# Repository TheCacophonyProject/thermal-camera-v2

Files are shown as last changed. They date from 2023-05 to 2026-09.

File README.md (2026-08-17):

# thermal-camera-v2

## Running tc2-panel.py (KiKit)

`tc2-panel.py` uses [KiKit](https://yaqwsx.github.io/KiKit/) to build the manufacturing panel from the individual board files.

```sh
# Create a venv that inherits the system site-packages (needed for pcbnew)
python3 -m venv --system-site-packages ~/.venvs/kikit
source ~/.venvs/kikit/bin/activate

# Install kikit and the other packages tc2-panel.py needs.
# pcbnewTransition is pinned >=0.5 because older versions assume a pre-KiCad-6
# pcbnew API (e.g. DRAWSEGMENT) and crash against current KiCad.
pip install kikit shapely "pcbnewTransition>=0.5"
```

Once the venv exists, running the panel script again only needs:

```sh
source ~/.venvs/kikit/bin/activate
cd /path/to/thermal-camera-v2
python3 tc2-panel.py
```

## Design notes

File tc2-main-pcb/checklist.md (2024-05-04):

# KiCAD Checklist for tc2-main-pcb

## High Priority
- [ ] Add smaller SMD nut for the modem as it is on the underside and might fall off. Also make it so no copper is on the other side to conduct through the heat when going through the oven.
- [ ] Add battery JLC number
- [x] Add 12 pin power connector JLC number
- [x] Move mounting hole above Modem
- [x] Move LED and button down a mm

## Future Enhancements
- [ ] Bed of nails pads for testing
- [ ] Reduce power usage in sleep mode
- [ ] Disable UART multiplexer chip when Raspberry pi is powered off
- [ ] Make issue about single lable not causing errors when the single lable is attached to multiple pins
- [x] Improve crystal time
- [ ] Add Cacophony logo
- [ ] Add version variable on PCB when it can be set through kicad-cli

## Pre-release checklist
- [ ] Check pinout to power board matches
- [ ] Set TAG
- [ ] Check that components have LCSC part numbers

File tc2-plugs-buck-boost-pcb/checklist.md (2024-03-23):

# KiCAD Checklist for tc2-buck-boost-pcb

## Release Tasks
- [x] Add version variable on PCB

## Future Enhancements
- [x] Better protection for RPi pins
- [ ] Bed of nails pads for testing
- [ ] Add Cacophony logo

## Pre-release checklist
- [ ] Check pinout to power board matches
- [ ] Check power layout
- [ ] Improve courtyard of plugs on bottom side.

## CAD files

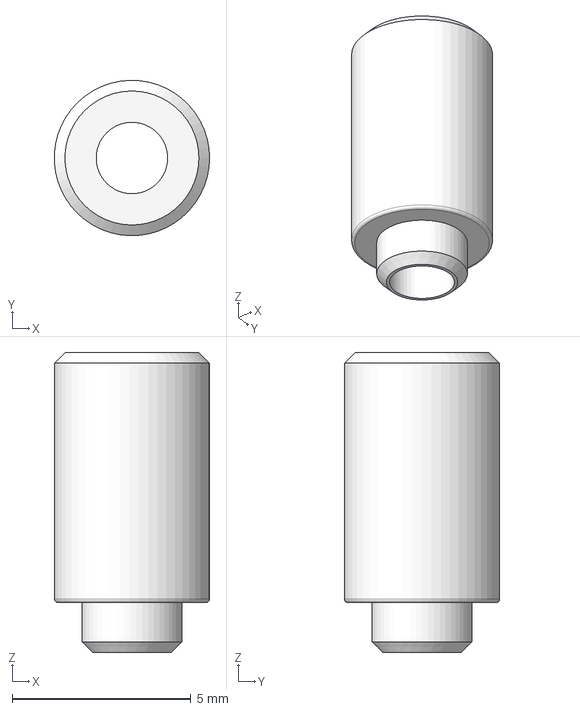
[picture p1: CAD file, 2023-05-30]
tc2-mic-pcb/drawings/7mm_2mm_nut.FCStd
4.35 x 4.35 x 8.40 mm

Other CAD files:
tc2-main-pcb/drawings/tc2-main.pcb.FCStd
tc2-mic-pcb/drawings/tc2-mic-pcb.FCStd
tc2-plugs-buck-boost-pcb/drawings/tc2-plugs-buck-boost-pcb.FCStd
tc2-plugs-pcb/drawings/tc2-plugs-pcb.FCStd
tc2-sim-usb-pcb/drawings/tc2-sim-usb-pcb.FCStd
tc2-sim-usb-pi3-pcb/drawings/tc2-sim-usb-pi3-pcb.FCStd
tc2-sim-usb-pi3-pcb/tc2-sim-usb-pi3-boarder.FCStd

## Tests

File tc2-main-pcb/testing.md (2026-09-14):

# Testing PCB

This is out of date but some parte might still be useful.

Fresh install of Raspberry Pi 64 Bit

## I2C

- `sudo apt install i2c-tools`
- `sudo raspi-conf` enable I2C
- `i2c detect -y 1`
- Check that you can see the addressed of all the devices
- Done

### Temp and Humidity Sensor

- Can get code to test sensor from [tc2-hat-software](https://github.com/TheCacophonyProject/tc2-hat-software)

### RTC

Add to `/etc/boot.conf` on raspberry pi

``` conf
# Enable RTC
dtoverlay=i2c-rtc,pcf8563
```

### Speaker

- Drive GPIO4 HIGH to enable speaker
- `python`

``` python
import RPi.GPIO as GPIO
GPIO.setwarnings(False)
GPIO.setmode(GPIO.BCM)
GPIO.setup(4, GPIO.OUT)
GPIO.output(4, True)
```

- Follow [Adafruit setup instructions](https://learn.adafruit.com/adafruit-max98357-i2s-class-d-mono-amp/raspberry-pi-usage)

### TODO

- EEPROM

## ATtiny1616

### ATtiny1616 RPi Setup

- `sudo apt install python3-pip -y`
- `pip install pymcuprog`
- Free up UART to be used for UPDI connection. Add `dtoverlay=disable-bt` to the end of `/boot/config.txt`
- Disable UART outputting to console: Remove `console=serial0,115200` from `/boot/cmdline.txt` and reboot.
- [pymcprog](https://github.com/microchip-pic-avr-tools/pymcuprog)
- Ping `sudo pymcuprog -d attiny1616 -t uart -u /dev/serial0 ping`
- Erase `sudo pymcuprog -d attiny1616 -t uart -u /dev/serial0 erase`
- Program through UPDI `sudo pymcuprog -d attiny1616 -t uart -u /dev/serial0 write -f ./Blink-attiny1616.ino.t1616.20c0.mD0.v261.hex`
- Note that you should Erase before programming each time.

### ATtiny1616 Testing

- [x] LED
- [] I2C minion
- [] RTC INT
- [] Battery voltage

### ATtiny1616 TODO

- [] Change programming to UPDI instead of ISP
- [] Fix LED pinout for colors
- [] Smaller resistors for LED

## Modem

- [Blog with setup instructions](https://www.elementzonline.com/blog/using-gps-antenna-with-sim7600-4g-lte-modem-v2-0)
- Enable by driving pin `4G_POWER_ON` HIGH
- [Waveshare wiki](https://www.waveshare.com/wiki/SIM7600G-H-M.2)
  - `sudo apt-get install minicom`
  - `sudo minicom -D /dev/ttyUSB2`
  - `AT+CUSBPIDSWITCH=9011,1,1`
  - `sudo dhclient -v usb0`
    AT+CMEE=2

### Modem Testing

- [x] GPS
- [x] 4G

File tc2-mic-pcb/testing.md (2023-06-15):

## Audio
### Microphone
- https://learn.adafruit.com/adafruit-i2s-mems-microphone-breakout/raspberry-pi-wiring-test
- `sudo apt install python3-pip`
- `sudo pip3 install --upgrade adafruit-python-shell`
- `wget https://raw.githubusercontent.com/adafruit/Raspberry-Pi-Installer-Scripts/master/i2smic.py`
- `sudo python3 i2smic.py` Auto load at boot? Y, Reboot now? Y
- Drive GPI17 HIGH to stop LORA module from interfering with the microphone as some of the pins are used for moth modules.
- `python`

Might have to change pins.
```
import RPi.GPIO as GPIO
GPIO.setwarnings(False)
GPIO.setmode(GPIO.BCM)
GPIO.setup(4, GPIO.OUT)
GPIO.output(4, True)
```

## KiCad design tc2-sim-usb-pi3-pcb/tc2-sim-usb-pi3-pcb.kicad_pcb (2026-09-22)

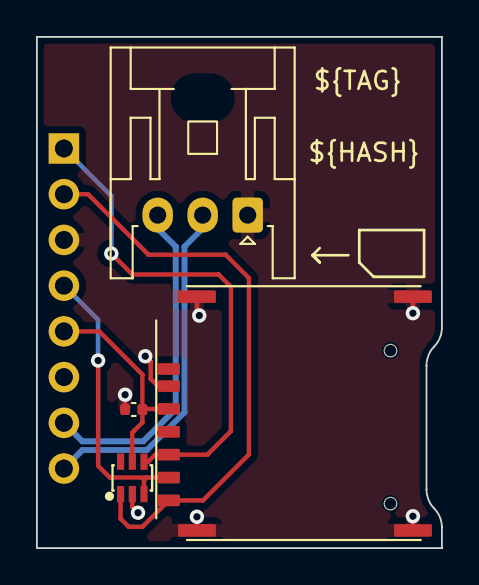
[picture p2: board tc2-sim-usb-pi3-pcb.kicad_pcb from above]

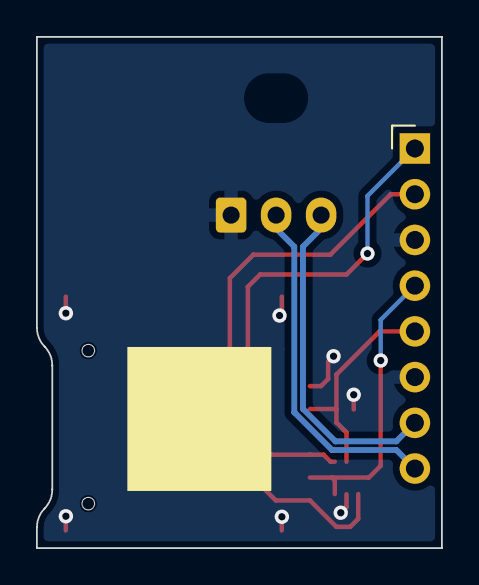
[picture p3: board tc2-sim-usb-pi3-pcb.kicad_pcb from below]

Board: 4 copper layers, 22.5 x 28.4 mm, 6 parts (2 on the bottom side), 7 nets.

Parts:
C1: 220nF; C_0402_1005Metric
D1: SMF05CT1G; SOT-363_L2.0-W1.3-P0.65-LS2.1-BR
J1: Conn_01x08; rpi3-usb-sim-PinHeader_1x08
J2: Conn_01x03; JST_XA_S03B-XASK-1_1x03_P2.50mm_Horizontal
U1: K-DYX-010
U2: JLCPCB_QR_8mm

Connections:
4G_USB_D+: J1.7, J2.3
4G_USB_D-: J1.8, J2.2
GND: C1.1, D1.2, J1.3, J1.6, J2.1, U1.C5 (Gnd), U1.MP, U1.MP_2 (MP), U1.MP_3 (MP), U1.MP_4 (MP)
USIM_CLK: D1.1, J1.2, U1.C3 (CLK)
USIM_DATA: D1.3, J1.4, U1.C7 (I/O)
USIM_RST: D1.4, J1.1, U1.C2 (RST)
USIM_VDD: C1.2, D1.5, J1.5, U1.C1 (Vcc)

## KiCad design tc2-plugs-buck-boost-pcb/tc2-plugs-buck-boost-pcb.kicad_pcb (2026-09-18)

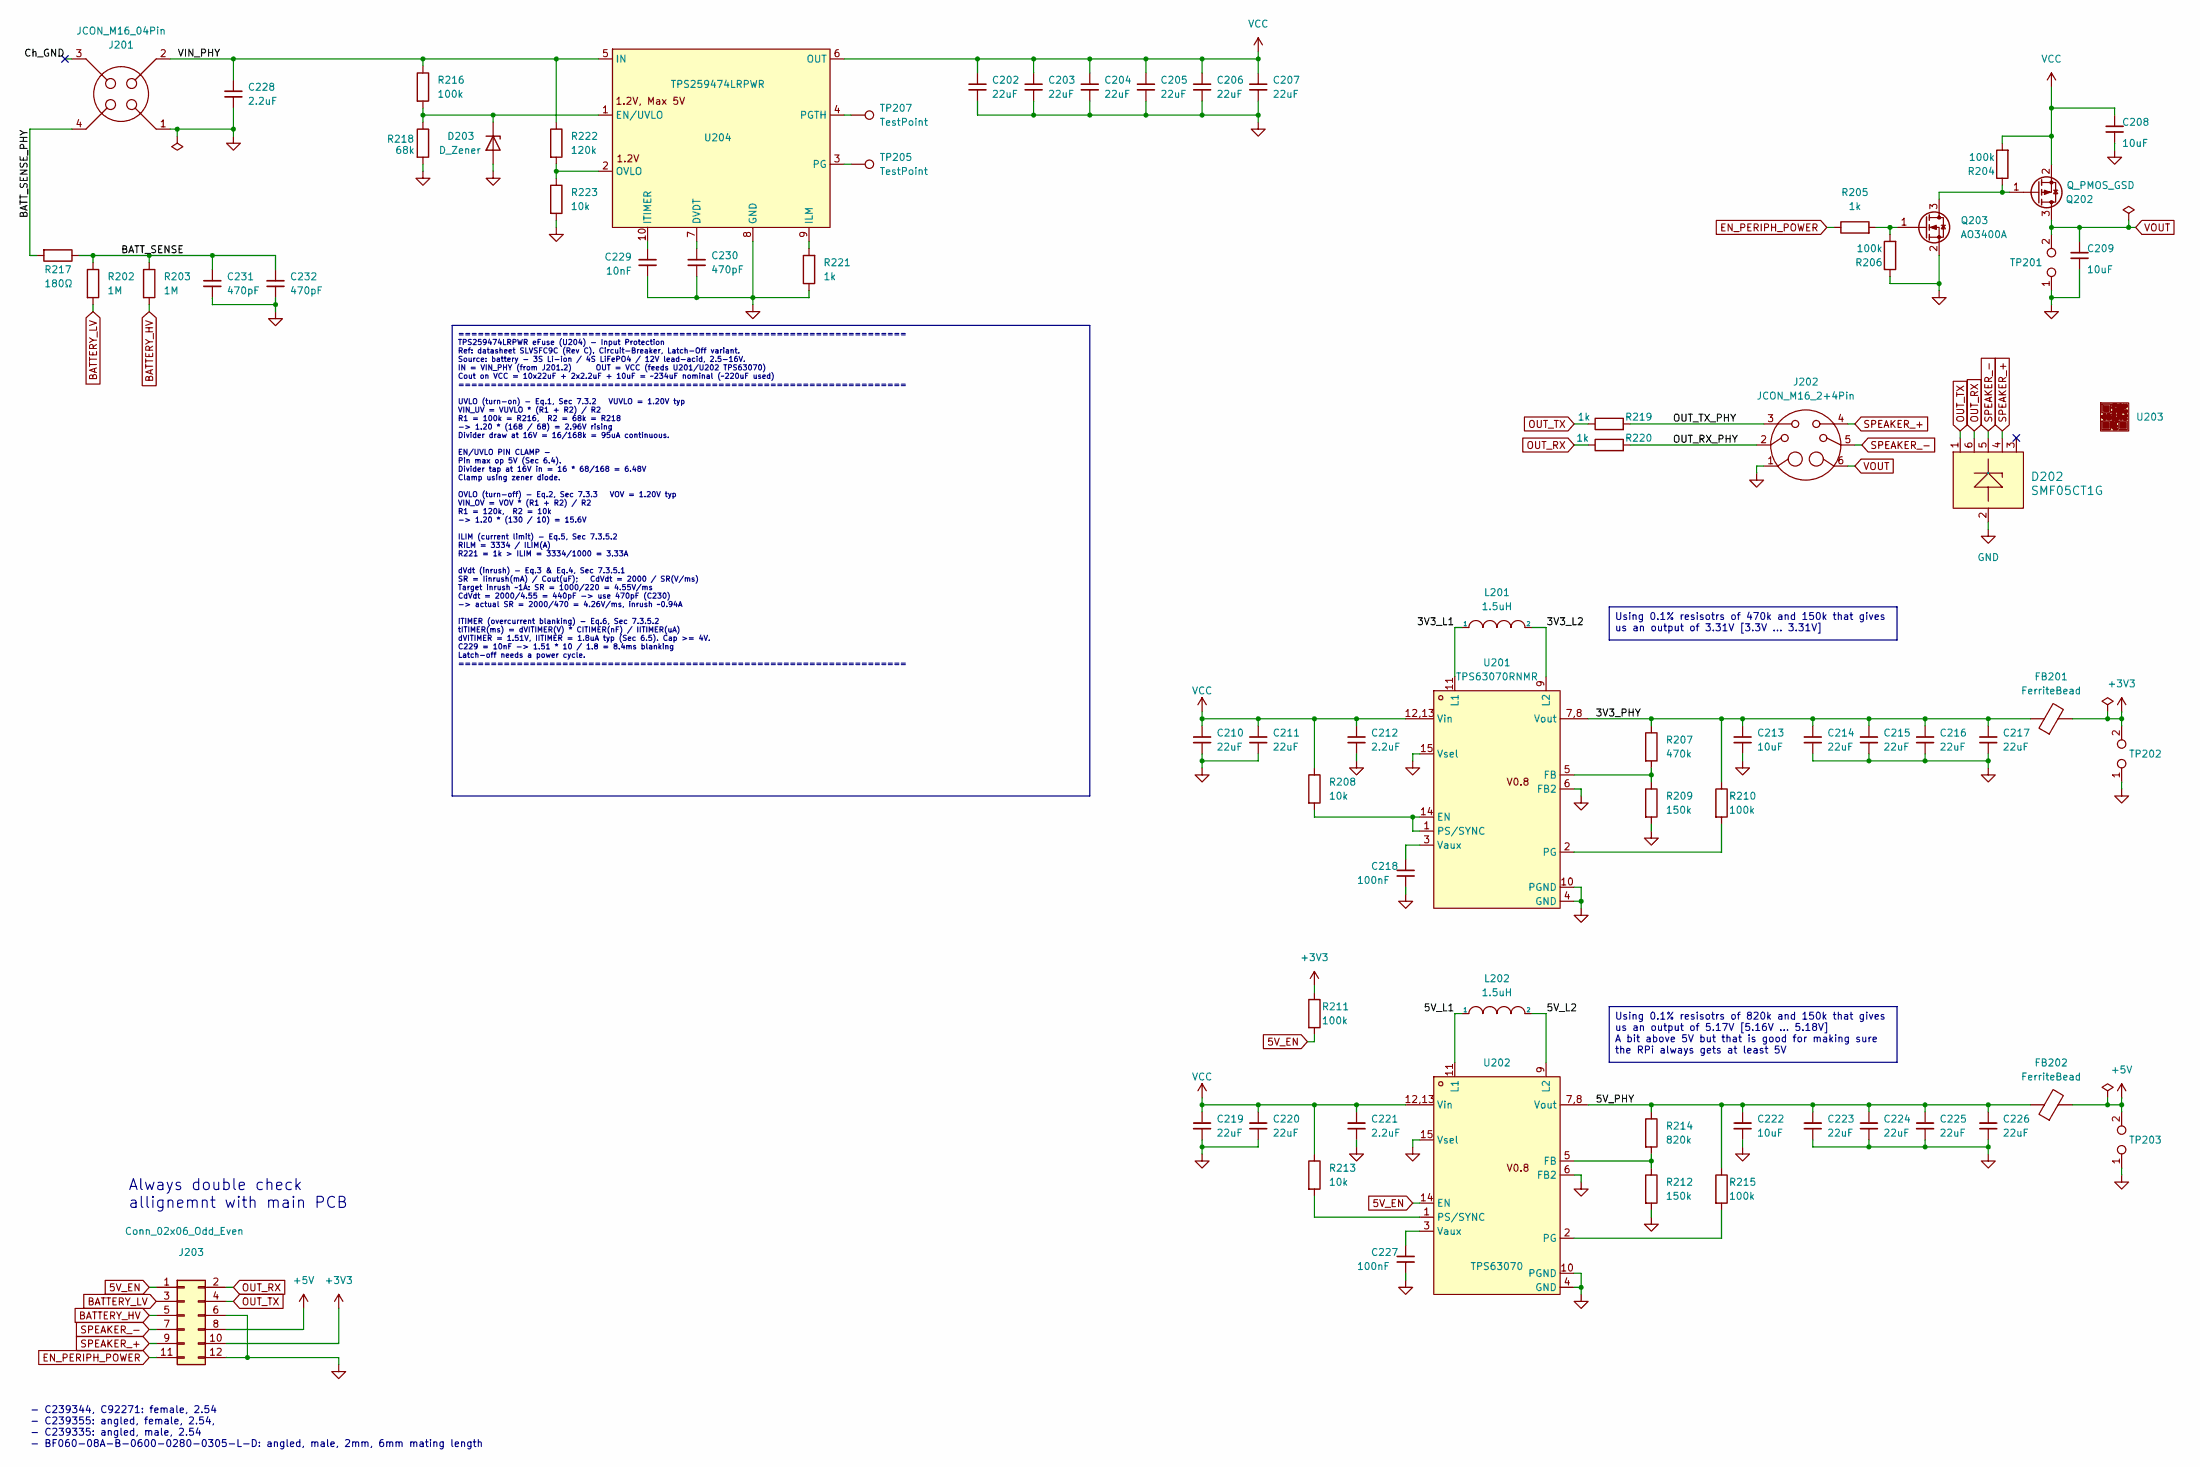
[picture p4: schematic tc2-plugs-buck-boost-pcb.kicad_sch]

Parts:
C202, C203, C204, C205, C206, C207, C210, C211, C219, C220: 22uF; C_0805_2012Metric; LCSC Part C45783
C208, C209: 10uF; C_0603_1608Metric; LCSC Part C19702
C212, C221, C228: 2.2uF; C_0402_1005Metric; LCSC Part C159814
C213, C222: 10uF; C_0402_1005Metric; LCSC Part C15525
C214, C215, C216, C217, C223, C224, C225, C226: 22uF; C_0603_1608Metric; LCSC Part C86295
C218, C227: 100nF; C_0402_1005Metric; LCSC Part C100072
C229: 10nF; C_0402_1005Metric; LCSC Part C15195
C230, C231, C232: 470pF; C_0402_1005Metric; LCSC Part C1537
D202: SMF05CT1G; SOT-363_L2.0-W1.3-P0.65-LS2.1-BR; LCSC Part C15879
D203: D_Zener; D_SOD-323; LCSC Part C136181
FB201, FB202: FerriteBead; L_0805_2012Metric; LCSC Part C76818
J201: JCON_M16_04Pin; jcon-4pin_m16
J202: JCON_M16_2+4Pin; jcon-2+4pin-m16
J203: Conn_02x06_Odd_Even; PinHeader_2x06_P2.00mm_Horizontal; Digikey 2073-BF060-12A-B-0600-0280-0305-L-D-ND
L201, L202: 1.5uH; L_1008_2520Metric; LCSC Part C5179452
Q202: Q_PMOS_GSD; SOT-23; LCSC Part C15127
Q203: AO3400A; SOT-23; LCSC Part C20917
R202, R203: 1M; R_0603_1608Metric; LCSC Part C326730
R204, R206, R210, R211, R215, R216: 100k; R_0402_1005Metric; LCSC Part C25741
R205, R219, R220, R221: 1k; R_0402_1005Metric; LCSC Part C11702
R207: 470k; R_0402_1005Metric; LCSC Part C319591
R208, R213, R223: 10k; R_0402_1005Metric; LCSC Part C25744
R209, R212: 150k; R_0402_1005Metric; LCSC Part C723770
R214: 820k; R_0402_1005Metric; LCSC Part C4042952
R217: 180Ω; R_0402_1005Metric; LCSC Part C38941
R218: 68k; R_0402_1005Metric; LCSC Part C445618
R222: 120k; R_0402_1005Metric; LCSC Part C25750
TP201, TP202, TP203: TestPoint_2Pole; test-point-2p
TP205, TP207: TestPoint; TP_PAD
U201: TPS63070RNMR; TPS63070; LCSC Part C109322
U202: TPS63070; LCSC Part C109322
U203: JLCPCB_QR_8mm
U204: TPS259474LRPWR; VQFN-10_L2.0-W2.0-P0.45-TL; LCSC Part C2864845

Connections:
5V_EN: J203.1, R211.2, U202.14 (EN)
+3V3: FB201.2, J203.10, R211.1, TP202.2
+5V: FB202.2, J203.8, TP203.2
/3V3_L1: L201.1, U201.11 (L1)
/3V3_L2: L201.2, U201.9 (L2)
/3V3_PHY: C213.1, C214.1, C215.1, C216.1, C217.1, FB201.1, R207.1, R210.1, U201.7,8 (Vout)
/5V_L1: L202.1, U202.11 (L1)
/5V_L2: L202.2, U202.9 (L2)
/5V_PHY: C222.1, C223.1, C224.1, C225.1, C226.1, FB202.1, R214.1, R215.1, U202.7,8 (Vout)
/BATT_SENSE: C231.1, C232.1, R202.1, R203.1, R217.1
/BATT_SENSE_PHY: J201.4, R217.2
/Ch_GND: J201.3
/OUT_RX_PHY: J202.2, R220.2
/OUT_TX_PHY: J202.3, R219.2
/VIN_PHY: C228.1, J201.2, R216.1, R222.1, U204.5 (IN)
BATTERY_HV: J203.5, R203.2
BATTERY_LV: J203.3, R202.2
EN_PERIPH_POWER: J203.11, R205.1
GND: C202.2, C203.2, C204.2, C205.2, C206.2, C207.2, C208.2, C209.2, C210.2, C211.2, C212.2, C213.2, C214.2, C215.2, C216.2, C217.2, C218.2, C219.2, C220.2, C221.2, C222.2, C223.2, C224.2, C225.2, C226.2, C227.2, C228.2, C229.2, C230.2, C231.2, C232.2, D202.2, D203.2 (A), J201.1, J202.1, J203.6, J203.12, Q203.2 (S), R206.1, R209.2, R212.2, R218.2, R221.1, R223.2, TP201.1, TP202.1, TP203.1, U201.4 (GND), U201.6 (FB2), U201.10 (PGND), U201.15 (Vsel), U202.4 (GND), U202.6 (FB2), U202.10 (PGND), U202.15 (Vsel), U204.8 (GND)
unnamed: D203.1 (K), R216.2, R218.1, U204.1 (EN/UVLO)
unnamed: Q202.1 (G), Q203.3 (D), R204.1
unnamed: Q203.1 (G), R205.2, R206.2
unnamed: R208.2, U201.1 (PS/SYNC), U201.14 (EN)
unnamed: R207.2, R209.1, U201.5 (FB)
unnamed: R210.2, U201.2 (PG)
unnamed: C218.1, U201.3 (Vaux)
unnamed: R212.1, R214.2, U202.5 (FB)
unnamed: R215.2, U202.2 (PG)
unnamed: R213.2, U202.1 (PS/SYNC)
unnamed: C227.1, U202.3 (Vaux)
unnamed: C230.1, U204.7 (DVDT)
unnamed: R221.2, U204.9 (ILM)
unnamed: C229.1, U204.10 (ITIMER)
unnamed: R222.2, R223.1, U204.2 (OVLO)
unnamed: TP205.1 (1_1), U204.3 (PG)
unnamed: TP207.1 (1_1), U204.4 (PGTH)
OUT_RX: D202.6, J203.2, R220.1
OUT_TX: D202.1, J203.4, R219.1
SPEAKER_+: D202.4, J202.4, J203.9
SPEAKER_-: D202.5, J202.5, J203.7
VCC: C202.1, C203.1, C204.1, C205.1, C206.1, C207.1, C208.1, C210.1, C211.1, C212.1, C219.1, C220.1, C221.1, Q202.2 (S), R204.2, R208.1, R213.1, U201.12,13 (Vin), U202.12,13 (Vin), U204.6 (OUT)
VOUT: C209.1, J202.6, Q202.3 (D), TP201.2

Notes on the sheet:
Always double check allignemnt with main PCB
- C239344, C92271: female, 2.54 - C239355: angled, female, 2.54, - C239335: angled, male, 2.54 - BF060-08A-B-0600-0280-0305-L-D: angled, male, 2mm, 6mm mating length
===================================================================== TPS259474LRPWR eFuse (U204) - Input Protection Ref: datasheet SLVSFC9C (Rev C). Circuit-Breaker, Latch-Off variant. Source: battery - 3S Li-ion / 4S LiFePO4 / 12V lead-acid, 2.5-16V. IN = VIN_PHY (from J201.2) OUT = VCC (feeds U2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
Using 0.1% resisotrs of 470k and 150k that gives us an output of 3.31V [3.3V ... 3.31V]
Using 0.1% resisotrs of 820k and 150k that gives us an output of 5.17V [5.16V ... 5.18V] A bit above 5V but that is good for making sure the RPi always gets at least 5V

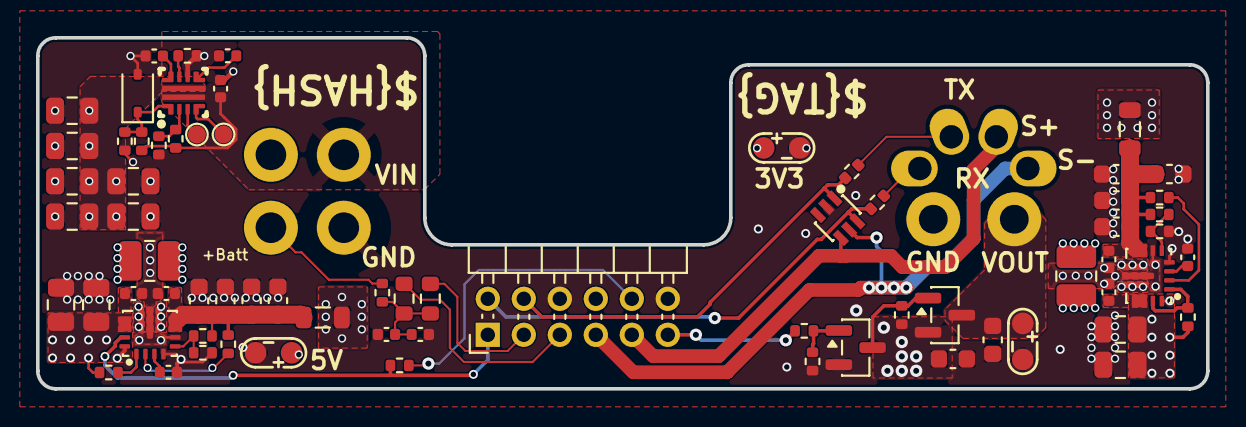
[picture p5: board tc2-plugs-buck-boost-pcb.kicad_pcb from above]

Board: 6 copper layers, 65.0 x 19.5 mm, 73 parts (1 on the bottom side), 41 nets.

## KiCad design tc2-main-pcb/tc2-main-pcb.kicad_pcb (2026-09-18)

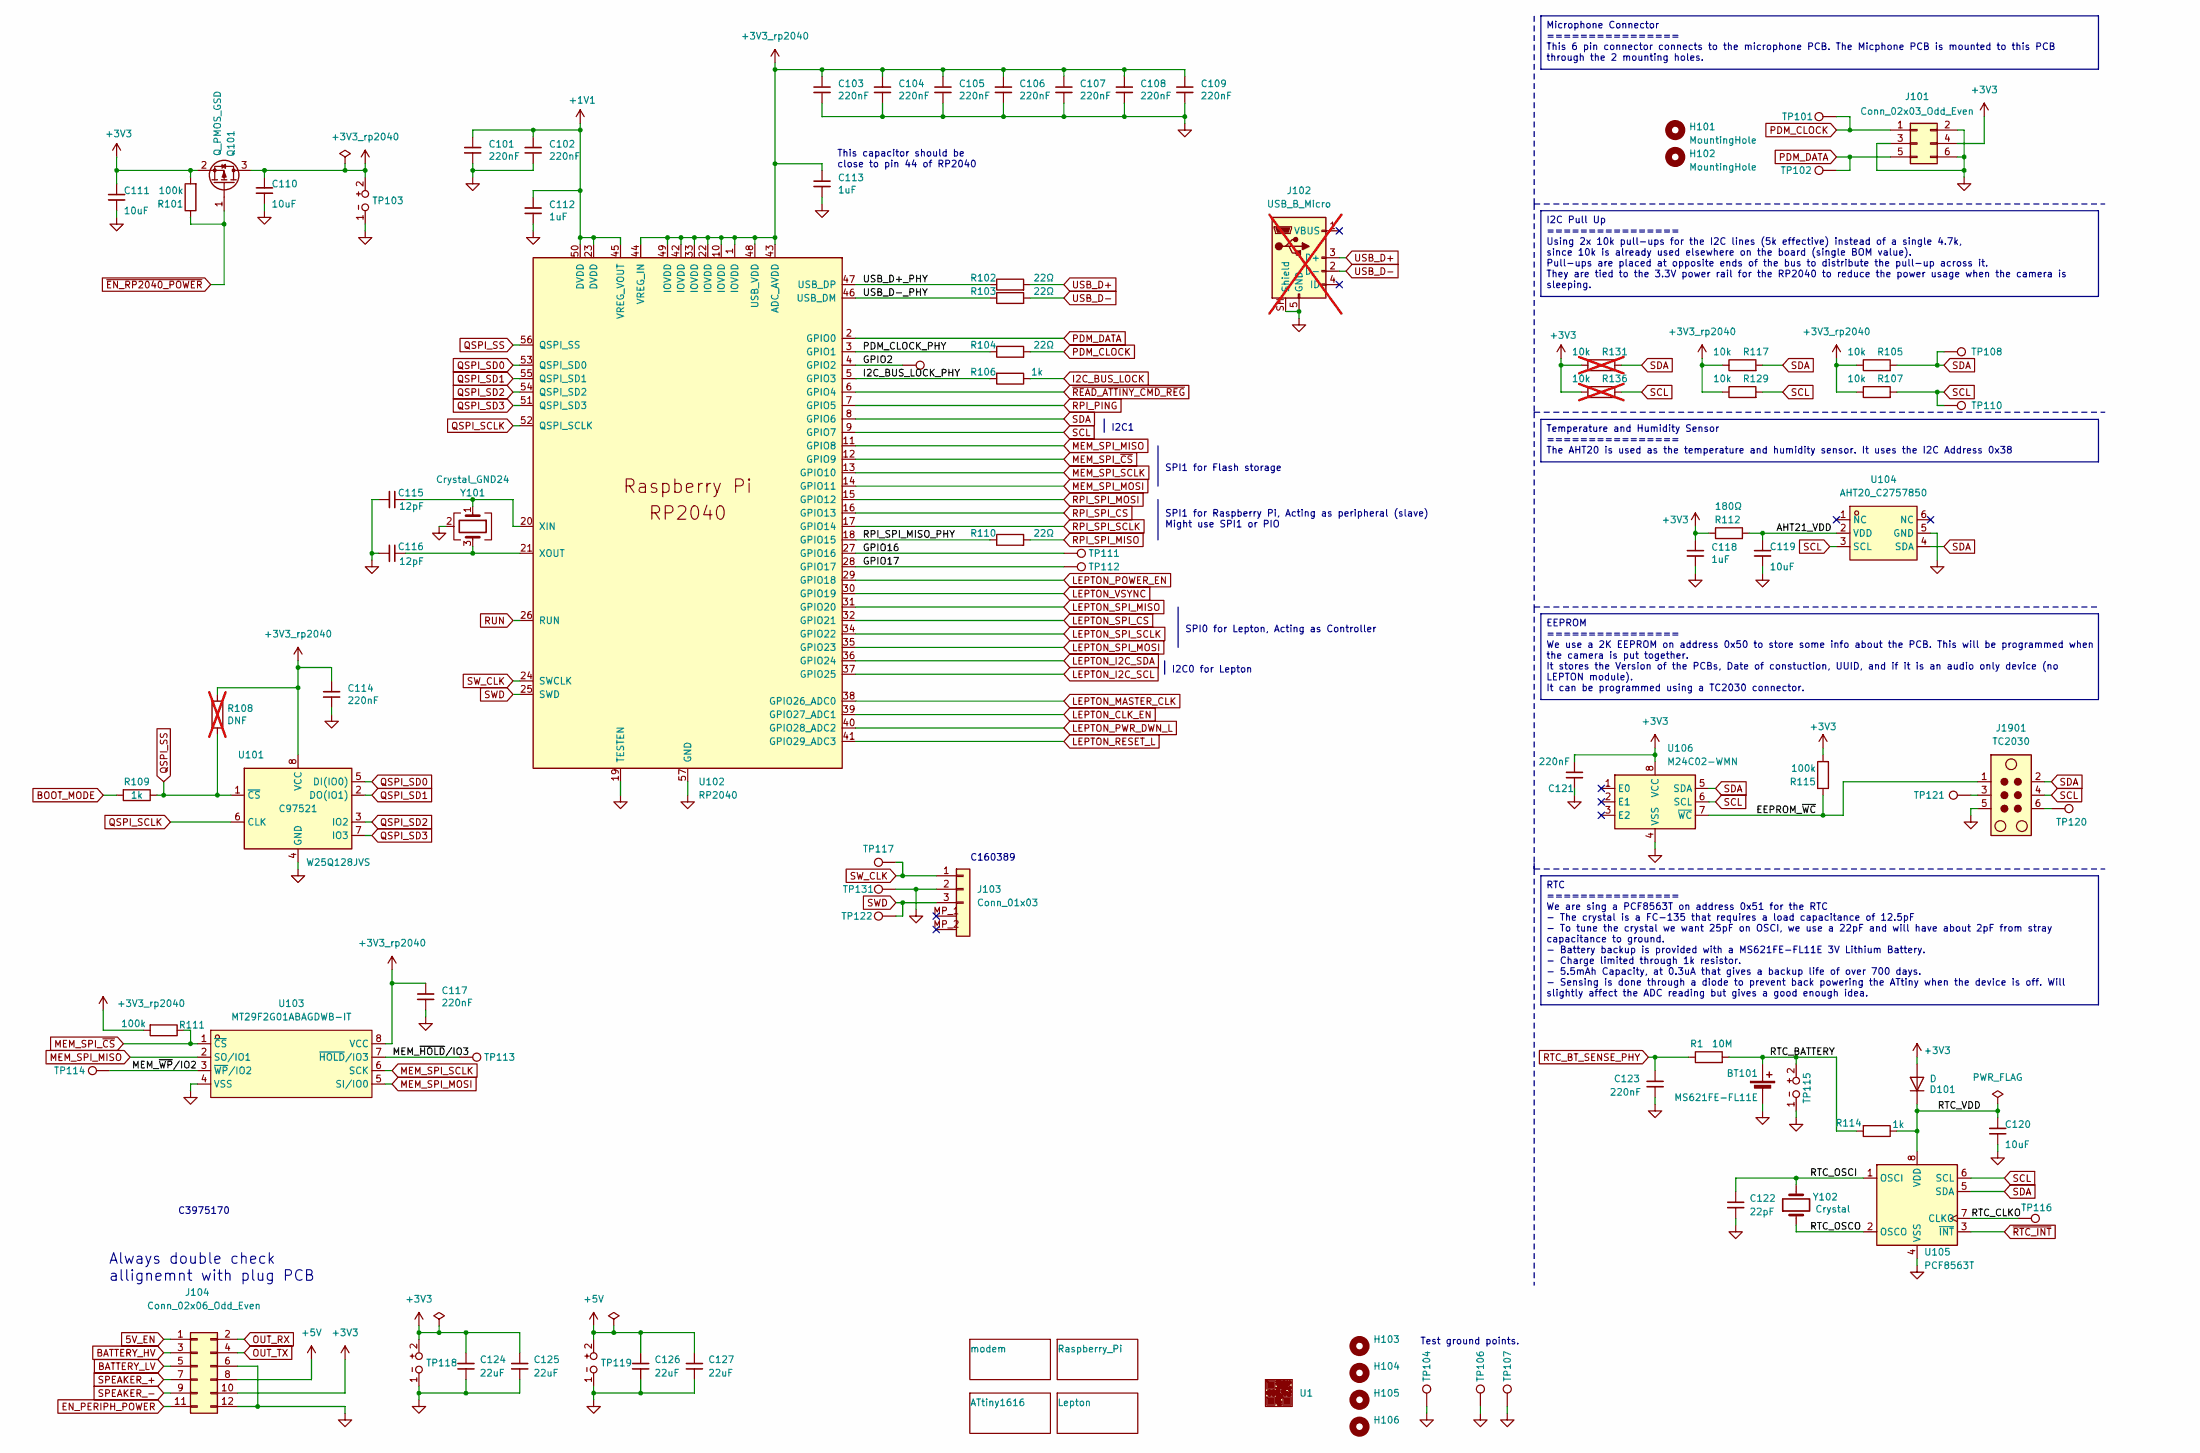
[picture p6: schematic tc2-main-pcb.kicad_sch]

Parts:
BT101: MS621FE-FL11E; CAP-SMD_FL11E; LCSC Part C80909
C101, C102, C103, C104, C105, C106, C107, C108, C109, C114, C117, C121, C123: 220nF; C_0402_1005Metric; LCSC Part C16772
C110, C111, C119, C120: 10uF; C_0603_1608Metric; LCSC Part C19702
C112, C113, C118: 1uF; C_0402_1005Metric; LCSC Part C52923
C115, C116: 12pF; C_0402_1005Metric; LCSC Part C1547
C122: 22pF; C_0402_1005Metric; LCSC Part C1555
C124, C125, C126, C127: 22uF; C_0603_1608Metric; LCSC Part C86295
D101: D; D_SOD-523; LCSC Part C668989
H101, H102: MountingHole; MountingHole_2.2mm_M2
H103, H104, H105, H106: MountingHole; MountingHole_3.2mm_M3
J101: Conn_02x03_Odd_Even; mic-pcb; LCSC Part C3975129
J102: USB_B_Micro; MICRO-USB-TH_MICRO-USB-A14; LCSC Part C145795; not fitted
J103: Conn_01x03; JST_SH_BM03B-SRSS-TB_1x03-1MP_P1.00mm_Vertical; LCSC Part C160389
J104: Conn_02x06_Odd_Even; power-pcb-3.1; Digikey BF100-12-A-D-1-0640-L-C
J1901: TC2030; Tag-Connect_TC2030-IDC-NL_2x03_P1.27mm_Vertical
Q101: Q_PMOS_GSD; SOT-23; LCSC Part C15127
R1: 10M; R_0402_1005Metric; LCSC Part C274900
R101, R111, R115: 100k; R_0402_1005Metric; LCSC Part C25741
R102, R103, R104, R110: 22Ω; R_0402_1005Metric; LCSC Part C25092
R105, R107, R117, R129: 10k; R_0402_1005Metric; LCSC Part C25744
R106, R109, R114: 1k; R_0402_1005Metric; LCSC Part C11702
R108: DNF; R_0402_1005Metric; not fitted
R112: 180Ω; R_0402_1005Metric; LCSC Part C38941
R131, R136: 10k; R_0402_1005Metric; LCSC Part C25744; not fitted
TP101, TP102, TP108, TP110, TP117, TP120, TP121, TP122, TP131: TestPoint; TestPoint_Pad_D1.0mm
TP103, TP115, TP118, TP119: TP_2P; test-point-2p
TP104, TP106, TP107: TestPoint; TestPoint_Loop_D2.54mm_Drill1.5mm_Beaded
TP109, TP111, TP112, TP113, TP114, TP116: TestPoint; TP
U1: JLCPCB_QR_8mm
U101: W25Q128JVS; SOIC-8_5.3x5.3mm_P1.27mm; LCSC Part C97521
U102: RP2040; RP2040-QFN-56; LCSC Part C2040
U103: MT29F2G01ABAGDWB-IT; U-PDFN-8_L6.0-W8.0-P1.27-BL; JLC Part Extended Part
U104: AHT20_C2757850; SENSOR-SMD_L3.0-W3.0-P1.00-BR; LCSC Part C2757850
U105: PCF8563T; SOIC-8_3.9x4.9mm_P1.27mm; LCSC Part C7440
U106: M24C02-WMN; SOIC-8_3.9x4.9mm_P1.27mm; LCSC Part C7562
Y101: Crystal_GND24; Crystal_SMD_3225-4Pin_3.2x2.5mm; LCSC Part C9002
Y102: Crystal; Crystal_SMD_3215-2Pin_3.2x1.5mm; LCSC Part C32346

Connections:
5V_EN: J104.1; also elsewhere on the board
+1V1: C101.1, C102.1, C112.1, U102.23 (DVDD), U102.45 (VREG_VOUT), U102.50 (DVDD)
+3V3: C111.1, C118.1, C121.2, C124.1, C125.1, D101.2 (A), J101.4, J104.10, Q101.2 (S), R101.2, R112.1, R115.2, R131.1, R136.1, TP118.2, U106.8 (VCC); also elsewhere on the board
+3V3_rp2040: C103.1, C104.1, C105.1, C106.1, C107.1, C108.1, C109.1, C110.1, C113.1, C114.1, C117.1, Q101.3 (D), R105.1, R107.1, R108.1, R111.2, R117.1, R129.1, TP103.2, U101.8 (VCC), U102.1 (IOVDD), U102.10 (IOVDD), U102.22 (IOVDD), U102.33 (IOVDD), U102.42 (IOVDD), U102.43 (ADC_AVDD), U102.44 (VREG_IN), U102.48 (USB_VDD), U102.49 (IOVDD), U103.8 (VCC)
+5V: C126.1, C127.1, J104.8, TP119.2; also elsewhere on the board
/AHT21_VDD: C119.1, R112.2, U104.2 (VDD)
/EEPROM_~WC: J1901.1, R115.1, U106.7 (~WC)
/GPIO2: TP109.1 (1_1), U102.4 (GPIO2)
/GPIO16: TP111.1 (1_1), U102.27 (GPIO16)
/GPIO17: TP112.1 (1_1), U102.28 (GPIO17)
/I2C_BUS_LOCK_PHY: R106.2, U102.5 (GPIO3)
/MEM_~HOLD/IO3: TP113.1 (1_1), U103.7 (~HOLD/IO3)
/MEM_~WP/IO2: TP114.1 (1_1), U103.3 (~WP/IO2)
/PDM_CLOCK_PHY: R104.1, U102.3 (GPIO1)
/RPI_SPI_MISO_PHY: R110.1, U102.18 (GPIO15)
/RTC_BATTERY: BT101.1 (+), R1.2, R114.2, TP115.2
/RTC_CLKO: TP116.1 (1_1), U105.7 (CLKO)
/RTC_OSCI: C122.1, U105.1 (OSCI), Y102.2
/RTC_OSCO: U105.2 (OSCO), Y102.1
/RTC_VDD: C120.1, D101.1 (K), R114.1, U105.8 (VDD)
/USB_D+_PHY: R102.1, U102.47 (USB_DP)
/USB_D-_PHY: R103.1, U102.46 (USB_DM)
BATTERY_HV: J104.3; also elsewhere on the board
BATTERY_LV: J104.5; also elsewhere on the board
BOOT_MODE: R109.2; also elsewhere on the board
EN_PERIPH_POWER: J104.11; also elsewhere on the board
GND: BT101.2 (-), C101.2, C102.2, C103.2, C104.2, C105.2, C106.2, C107.2, C108.2, C109.2, C110.2, C111.2, C112.2, C113.2, C114.2, C115.1, C116.1, C117.2, C118.2, C119.2, C120.2, C121.1, C122.2, C123.2, C124.2, C125.2, C126.2, C127.2, J101.2, J101.3, J101.6, J102.5 (GND), J102.SH (Shield), J103.2, J104.6, J104.12, J1901.5, TP103.1, TP104.1 (1_1), TP106.1 (1_1), TP107.1 (1_1), TP115.1, TP118.1, TP119.1, TP131.1 (1_1), U101.4 (GND), U102.19 (TESTEN), U102.57 (GND), U103.4 (VSS), U104.5 (GND), U105.4 (VSS), U106.4 (VSS), Y101.2 (G), Y101.4 (G); also elsewhere on the board
I2C_BUS_LOCK: R106.1; also elsewhere on the board
LEPTON_CLK_EN: U102.39 (GPIO27_ADC1); also elsewhere on the board
LEPTON_I2C_SCL: U102.37 (GPIO25); also elsewhere on the board
LEPTON_I2C_SDA: U102.36 (GPIO24); also elsewhere on the board
LEPTON_MASTER_CLK: U102.38 (GPIO26_ADC0); also elsewhere on the board
LEPTON_POWER_EN: U102.29 (GPIO18); also elsewhere on the board
LEPTON_PWR_DWN_L: U102.40 (GPIO28_ADC2); also elsewhere on the board
LEPTON_RESET_L: U102.41 (GPIO29_ADC3); also elsewhere on the board
LEPTON_SPI_CS: U102.32 (GPIO21); also elsewhere on the board
LEPTON_SPI_MISO: U102.31 (GPIO20); also elsewhere on the board
LEPTON_SPI_MOSI: U102.35 (GPIO23); also elsewhere on the board
LEPTON_SPI_SCLK: U102.34 (GPIO22); also elsewhere on the board
LEPTON_VSYNC: U102.30 (GPIO19); also elsewhere on the board
MEM_SPI_MISO: U102.11 (GPIO8), U103.2 (SO/IO1)
MEM_SPI_MOSI: U102.14 (GPIO11), U103.5 (SI/IO0)
MEM_SPI_SCLK: U102.13 (GPIO10), U103.6 (SCK)
MEM_SPI_~CS: R111.1, U102.12 (GPIO9), U103.1 (~CS)
unnamed: J1901.3, TP121.1 (1_1)
unnamed: J1901.6, TP120.1 (1_1)
unnamed: C115.2, U102.20 (XIN), Y101.1
unnamed: C116.2, U102.21 (XOUT), Y101.3
OUT_RX: J104.2; also elsewhere on the board
OUT_TX: J104.4; also elsewhere on the board
PDM_CLOCK: J101.1, R104.2, TP101.1 (1_1)
PDM_DATA: J101.5, TP102.1 (1_1), U102.2 (GPIO0)
QSPI_SCLK: U101.6 (CLK), U102.52 (QSPI_SCLK)
QSPI_SD0: U101.5 (DI(IO0)), U102.53 (QSPI_SD0)
QSPI_SD1: U101.2 (DO(IO1)), U102.55 (QSPI_SD1)
QSPI_SD2: U101.3 (IO2), U102.54 (QSPI_SD2)
QSPI_SD3: U101.7 (IO3), U102.51 (QSPI_SD3)
QSPI_SS: R108.2, R109.1, U101.1 (~CS), U102.56 (QSPI_SS)
RPI_PING: U102.7 (GPIO5); also elsewhere on the board
RPI_SPI_CS: U102.16 (GPIO13); also elsewhere on the board
RPI_SPI_MISO: R110.2; also elsewhere on the board
RPI_SPI_MOSI: U102.15 (GPIO12); also elsewhere on the board
RPI_SPI_SCLK: U102.17 (GPIO14); also elsewhere on the board
RTC_BT_SENSE_PHY: C123.1, R1.1; also elsewhere on the board
RUN: U102.26 (RUN); also elsewhere on the board
SCL: J1901.4, R107.2, R129.2, R136.2, TP110.1 (1_1), U102.9 (GPIO7), U104.3 (SCL), U105.6 (SCL), U106.6 (SCL); also elsewhere on the board
SDA: J1901.2, R105.2, R117.2, R131.2, TP108.1 (1_1), U102.8 (GPIO6), U104.4 (SDA), U105.5 (SDA), U106.5 (SDA); also elsewhere on the board
SPEAKER_+: J104.7; also elsewhere on the board
SPEAKER_-: J104.9; also elsewhere on the board
SWD: J103.3, TP122.1 (1_1), U102.25 (SWD); also elsewhere on the board
SW_CLK: J103.1, TP117.1 (1_1), U102.24 (SWCLK); also elsewhere on the board
USB_D+: J102.3 (D+), R102.2
USB_D-: J102.2 (D-), R103.2
~EN_RP2040_POWER: Q101.1 (G), R101.1; also elsewhere on the board
~READ_ATTINY_CMD_REG: U102.6 (GPIO4); also elsewhere on the board
~RTC_INT: U105.3 (~INT); also elsewhere on the board

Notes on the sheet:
C160389
Test ground points.
SPI0 for Lepton, Acting as Controller
I2C1
C3975170
Always double check allignemnt with plug PCB
I2C0 for Lepton
This capacitor should be close to pin 44 of RP2040
SPI1 for Raspberry Pi, Acting as peripheral (slave) Might use SPI1 or PIO
SPI1 for Flash storage
I2C Pull Up ================ Using 2x 10k pull-ups for the I2C lines (5k effective) instead of a single 4.7k, since 10k is already used elsewhere on the board (single BOM value). Pull-ups are placed at opposite ends of the bus to distribute the pull-up across it. They are tied to the 3.3V power rai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
RTC ================ We are sing a PCF8563T on address 0x51 for the RTC - The crystal is a FC-135 that requires a load capacitance of 12.5pF - To tune the crystal we want 25pF on OSCI, we use a 22pF and will have about 2pF from stray capacitance to ground. - Battery backup is provided with a MS621F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
Temperature and Humidity Sensor ================ The AHT20 is used as the temperature and humidity sensor. It uses the I2C Address 0x38
Microphone Connector ================ This 6 pin connector connects to the microphone PCB. The Micphone PCB is mounted to this PCB through the 2 mounting holes.
EEPROM ================ We use a 2K EEPROM on address 0x50 to store some info about the PCB. This will be programmed when the camera is put together. It stores the Version of the PCBs, Date of constuction, UUID, and if it is an audio only device (no LEPTON module). It can be programmed using a TC20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

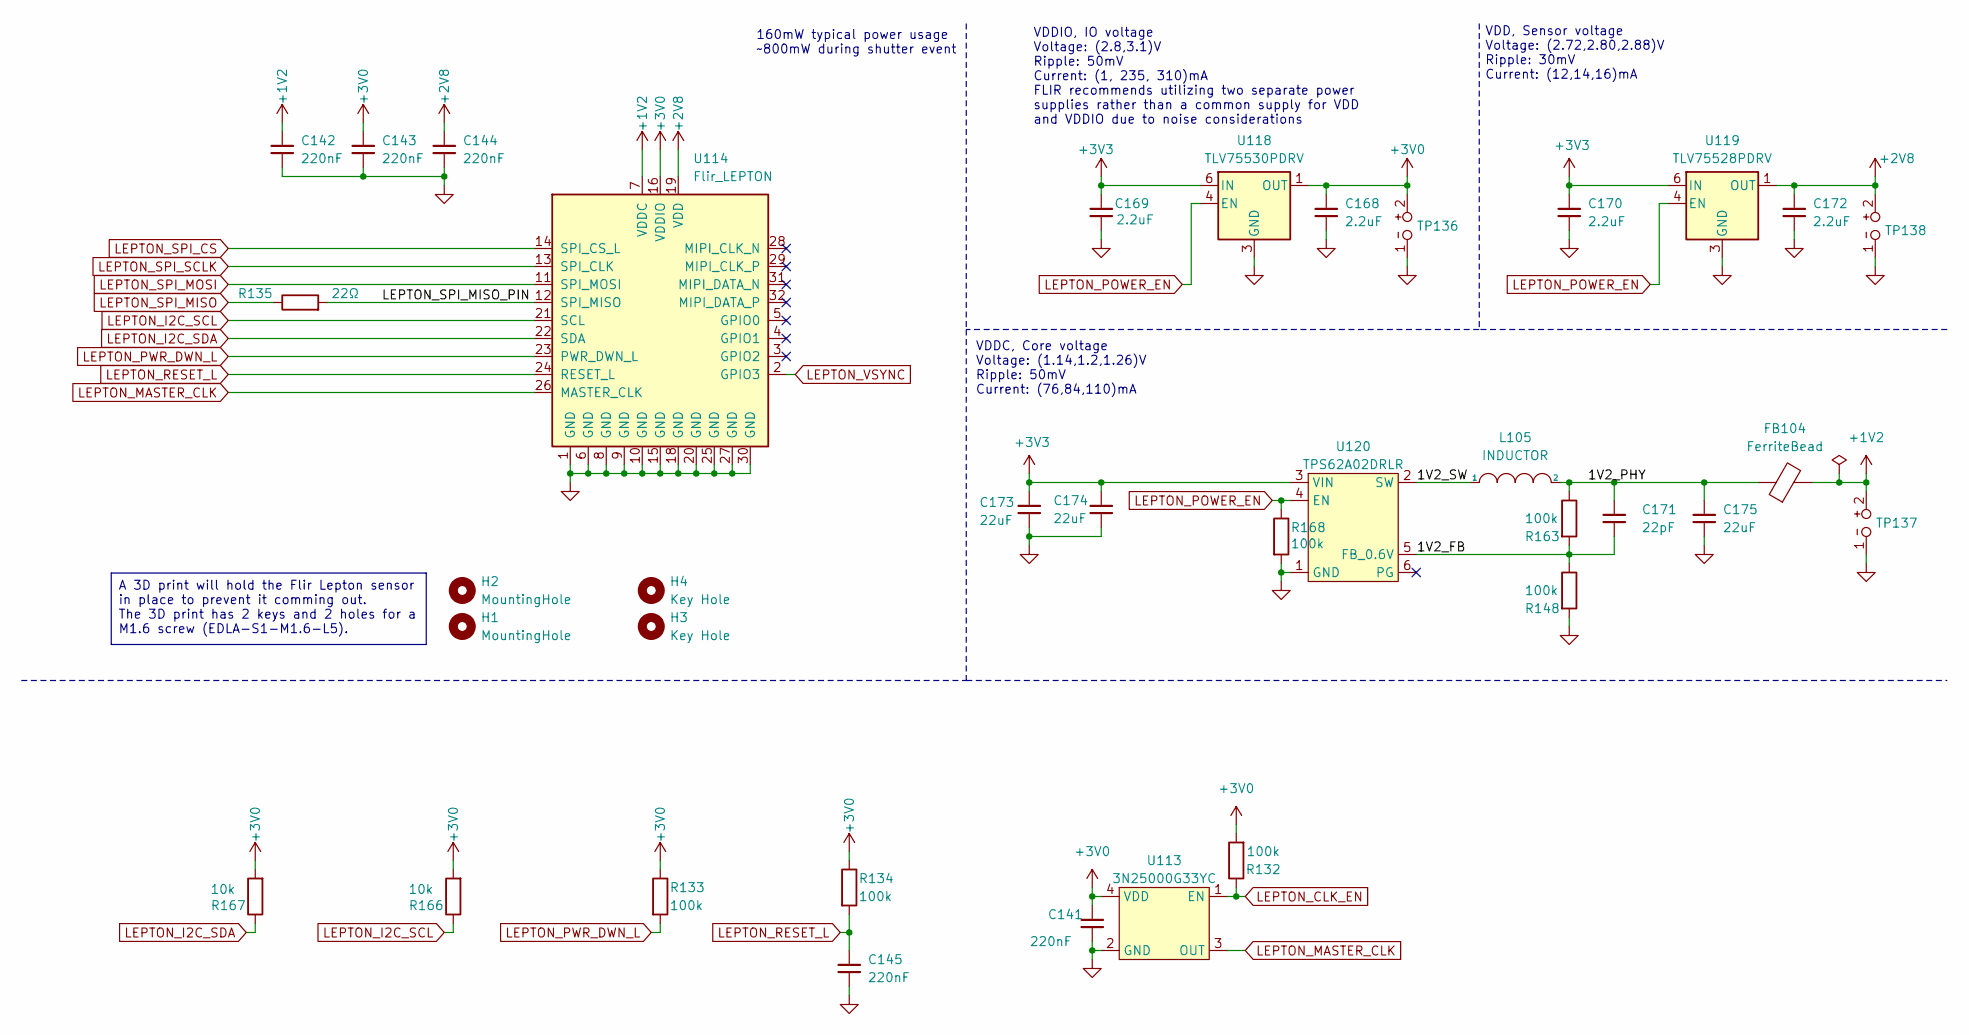
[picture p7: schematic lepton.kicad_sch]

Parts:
C141, C142, C143, C144, C145: 220nF; C_0402_1005Metric; LCSC Part C16772
C168, C169, C170, C172: 2.2uF; C_0402_1005Metric; LCSC Part C12530
C171: 22pF; C_0402_1005Metric; LCSC Part C1555
C173, C174, C175: 22uF; C_0603_1608Metric; LCSC Part C86295
FB104: FerriteBead; L_0805_2012Metric; LCSC Part C76818
H1, H2: MountingHole; MountingHole_1.8mm_M1.6
H3, H4: Key Hole; KeyHole_1.8mm
L105: INDUCTOR; L_1008_2520Metric; LCSC Part C285917
R132: 100k; R_0402_1005Metric; MPN RC1005F103CS; LCSC Part C25741
R133, R134, R148, R163, R168: 100k; R_0402_1005Metric; LCSC Part C25741
R135: 22Ω; R_0402_1005Metric; LCSC Part C25092
R166, R167: 10k; R_0402_1005Metric; LCSC Part C25744
TP136, TP137, TP138: TP_2P; test-point-2p
U113: 3N25000G33YC; Oscillator_SMD_Abracon_ASE-4Pin_3.2x2.5mm; JLCPCB C252341
U114: Flir_LEPTON; MOLEX_105028-1001; MPN 1050281001; LCSC Part C585422
U118: TLV75530PDRV; WSON-6-1EP_2x2mm_P0.65mm_EP1x1.6mm; LCSC Part C2859948
U119: TLV75528PDRV; WSON-6-1EP_2x2mm_P0.65mm_EP1x1.6mm; LCSC Part C2865214
U120: TPS62A02DRLR; SOT-563; LCSC Part C5350187

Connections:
+1V2: C142.1, FB104.2, TP137.2, U114.7 (VDDC)
+2V8: C144.1, C172.1, TP138.2, U114.19 (VDD), U119.1 (OUT)
+3V0: C141.1, C143.1, C168.1, R132.2, R133.1, R134.1, R166.2, R167.2, TP136.2, U113.4 (VDD), U114.16 (VDDIO), U118.1 (OUT)
+3V3: C169.1, C170.1, C173.1, C174.1, U118.6 (IN), U119.6 (IN), U120.3 (VIN); also elsewhere on the board
/Lepton/1V2_FB: C171.2, R148.1, R163.2, U120.5 (FB_0.6V)
/Lepton/1V2_PHY: C171.1, C175.1, FB104.1, L105.2, R163.1
/Lepton/1V2_SW: L105.1, U120.2 (SW)
/Lepton/LEPTON_SPI_MISO_PIN: R135.2, U114.12 (SPI_MISO)
GND: C141.2, C142.2, C143.2, C144.2, C145.2, C168.2, C169.2, C170.2, C172.2, C173.2, C174.2, C175.2, R148.2, R168.2, TP136.1, TP137.1, TP138.1, U113.2 (GND), U114.1 (GND), U114.6 (GND), U114.8 (GND), U114.9 (GND), U114.10 (GND), U114.15 (GND), U114.18 (GND), U114.20 (GND), U114.25 (GND), U114.27 (GND), U114.30 (GND), U118.3 (GND), U118.7 (GND), U119.3 (GND), U119.7 (GND), U120.1 (GND); also elsewhere on the board
LEPTON_CLK_EN: R132.1, U113.1 (EN); also elsewhere on the board
LEPTON_I2C_SCL: R166.1, U114.21 (SCL); also elsewhere on the board
LEPTON_I2C_SDA: R167.1, U114.22 (SDA); also elsewhere on the board
LEPTON_MASTER_CLK: U113.3 (OUT), U114.26 (MASTER_CLK); also elsewhere on the board
LEPTON_POWER_EN: R168.1, U118.4 (EN), U119.4 (EN), U120.4 (EN); also elsewhere on the board
LEPTON_PWR_DWN_L: R133.2, U114.23 (PWR_DWN_L); also elsewhere on the board
LEPTON_RESET_L: C145.1, R134.2, U114.24 (RESET_L); also elsewhere on the board
LEPTON_SPI_CS: U114.14 (SPI_CS_L); also elsewhere on the board
LEPTON_SPI_MISO: R135.1; also elsewhere on the board
LEPTON_SPI_MOSI: U114.11 (SPI_MOSI); also elsewhere on the board
LEPTON_SPI_SCLK: U114.13 (SPI_CLK); also elsewhere on the board
LEPTON_VSYNC: U114.2 (GPIO3); also elsewhere on the board

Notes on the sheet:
VDDIO, IO voltage Voltage: (2.8,3.1)V Ripple: 50mV Current: (1, 235, 310)mA FLIR recommends utilizing two separate power supplies rather than a common supply for VDD and VDDIO due to noise considerations
VDDC, Core voltage Voltage: (1.14,1.2,1.26)V Ripple: 50mV Current: (76,84,110)mA
VDD, Sensor voltage Voltage: (2.72,2.80,2.88)V Ripple: 30mV Current: (12,14,16)mA
160mW typical power usage ~800mW during shutter event
A 3D print will hold the Flir Lepton sensor in place to prevent it comming out. The 3D print has 2 keys and 2 holes for a M1.6 screw (EDLA-S1-M1.6-L5).

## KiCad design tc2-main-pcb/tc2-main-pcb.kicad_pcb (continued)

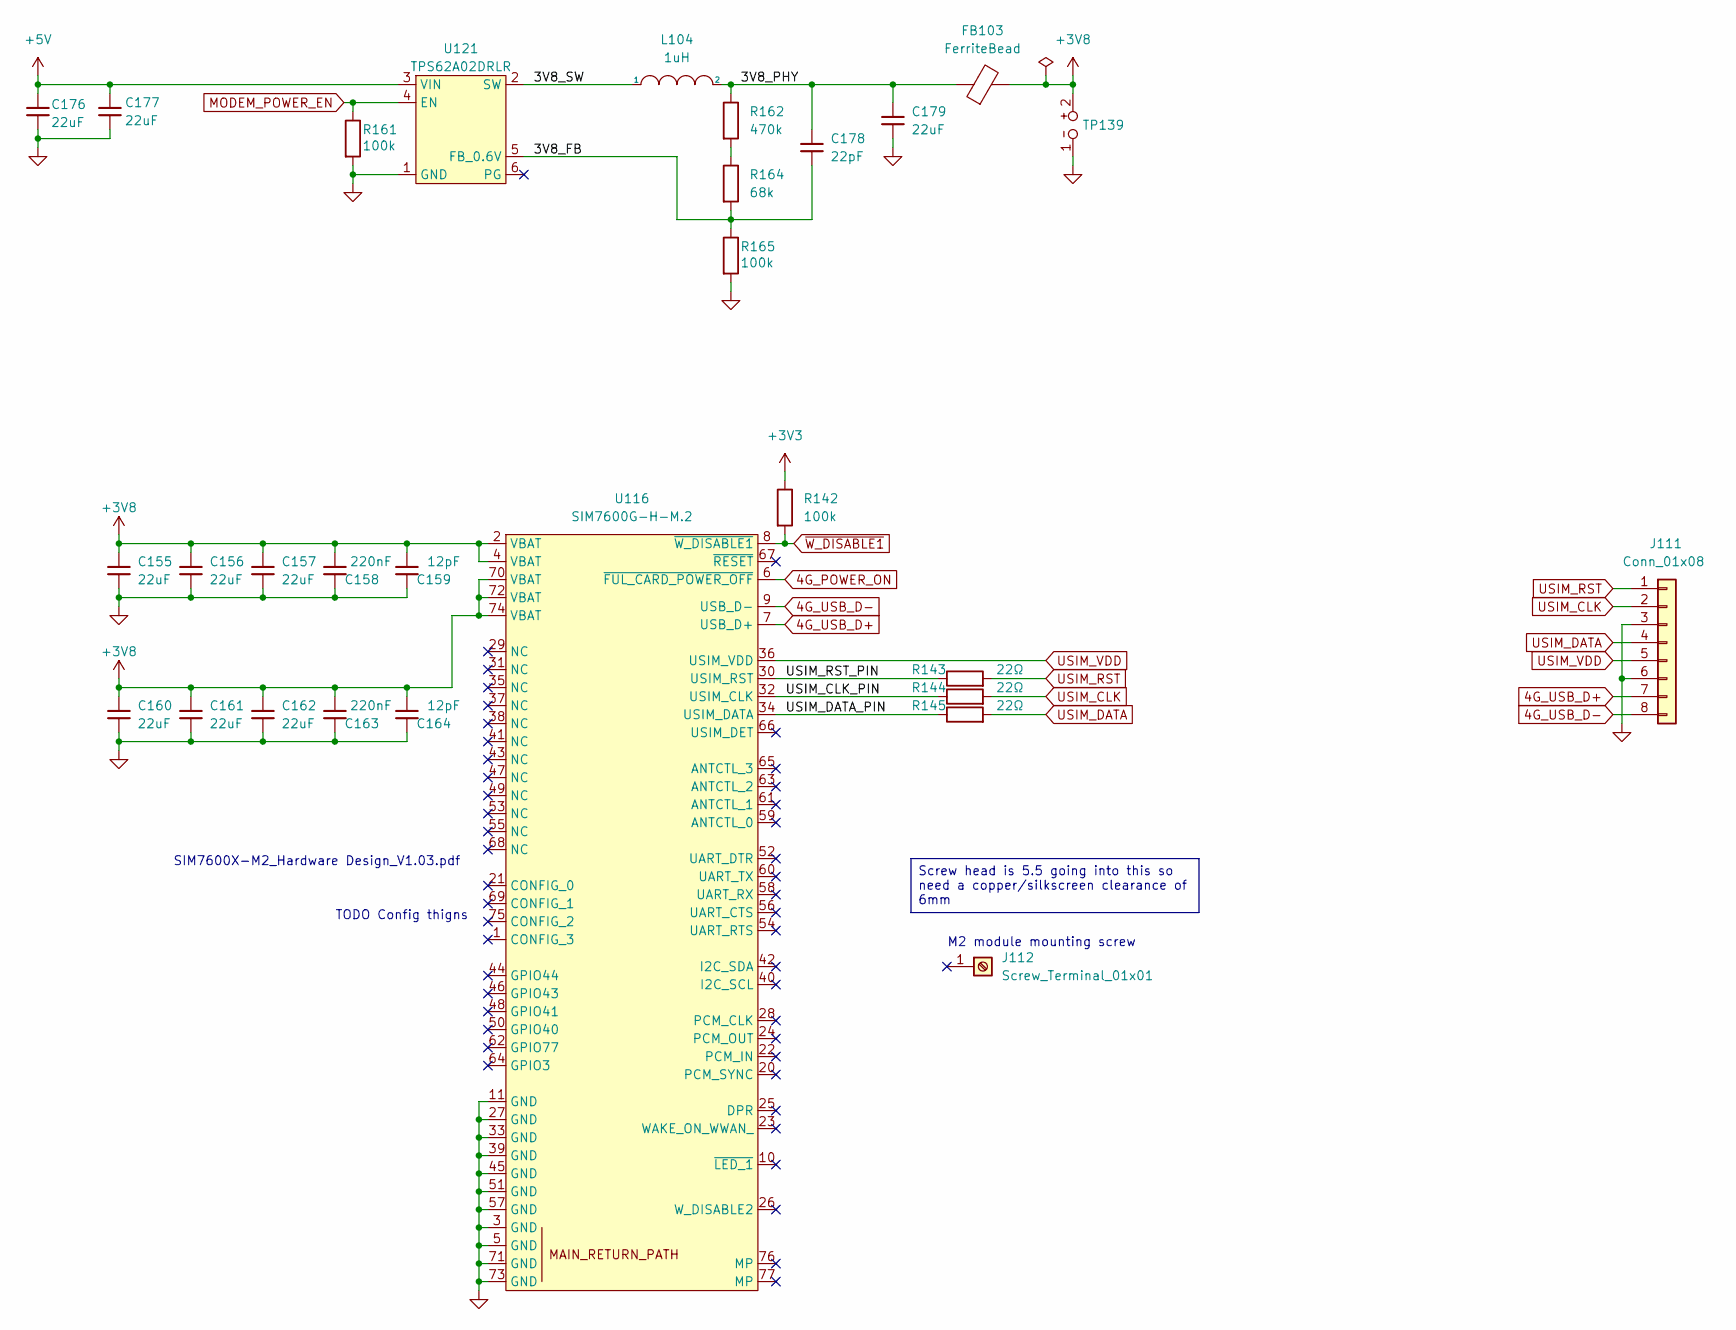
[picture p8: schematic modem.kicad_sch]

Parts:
C155, C156, C157, C160, C161, C162, C176, C177, C179: 22uF; C_0603_1608Metric; LCSC Part C86295
C158, C163: 220nF; C_0402_1005Metric; LCSC Part C16772
C159, C164: 12pF; C_0402_1005Metric; LCSC Part C1547
C178: 22pF; C_0402_1005Metric; LCSC Part C1555
FB103: FerriteBead; L_0805_2012Metric; LCSC Part C76818
J111: Conn_01x08; sim-usb-pcb
J112: Screw_Terminal_01x01; M2_modem_mount_screw; LCSC Part C2928176
L104: 1uH; L_1008_2520Metric; LCSC Part C285917
R142, R161, R165: 100k; R_0402_1005Metric; LCSC Part C25741
R143, R144, R145: 22Ω; R_0402_1005Metric; LCSC Part C25092
R162: 470k; R_0402_1005Metric; LCSC Part C319591
R164: 68k; R_0402_1005Metric; LCSC Part C445618
TP139: TP_2P; test-point-2p
U116: SIM7600G-H-M.2; M.2; LCSC Part C2761526
U121: TPS62A02DRLR; SOT-563; LCSC Part C5350187

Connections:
4G_POWER_ON: U116.6 (~FUL_CARD_POWER_OFF); also elsewhere on the board
4G_USB_D+: J111.7, U116.7 (USB_D+)
4G_USB_D-: J111.8, U116.9 (USB_D-)
+3V3: R142.1; also elsewhere on the board
+3V8: C155.1, C156.1, C157.1, C158.2, C159.2, C160.1, C161.1, C162.1, C163.2, C164.2, FB103.2, TP139.2, U116.2 (VBAT), U116.4 (VBAT), U116.70 (VBAT), U116.72 (VBAT), U116.74 (VBAT)
+5V: C176.1, C177.1, U121.3 (VIN); also elsewhere on the board
/modem/3V8_FB: C178.2, R164.2, R165.1, U121.5 (FB_0.6V)
/modem/3V8_PHY: C178.1, C179.1, FB103.1, L104.2, R162.1
/modem/3V8_SW: L104.1, U121.2 (SW)
/modem/USIM_CLK_PIN: R144.1, U116.32 (USIM_CLK)
/modem/USIM_DATA_PIN: R145.1, U116.34 (USIM_DATA)
/modem/USIM_RST_PIN: R143.1, U116.30 (USIM_RST)
GND: C155.2, C156.2, C157.2, C158.1, C159.1, C160.2, C161.2, C162.2, C163.1, C164.1, C176.2, C177.2, C179.2, J111.3, J111.6, R161.2, R165.2, TP139.1, U116.3 (GND), U116.5 (GND), U116.11 (GND), U116.27 (GND), U116.33 (GND), U116.39 (GND), U116.45 (GND), U116.51 (GND), U116.57 (GND), U116.71 (GND), U116.73 (GND), U121.1 (GND); also elsewhere on the board
MODEM_POWER_EN: R161.1, U121.4 (EN); also elsewhere on the board
unnamed: R162.2, R164.1
USIM_CLK: J111.2, R144.2
USIM_DATA: J111.4, R145.2
USIM_RST: J111.1, R143.2
USIM_VDD: J111.5, U116.36 (USIM_VDD)
~W_DISABLE1: R142.2, U116.8 (~W_DISABLE1); also elsewhere on the board

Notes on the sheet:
TODO Config thigns
M2 module mounting screw
SIM7600X-M2_Hardware Design_V1.03.pdf
Screw head is 5.5 going into this so need a copper/silkscreen clearance of 6mm

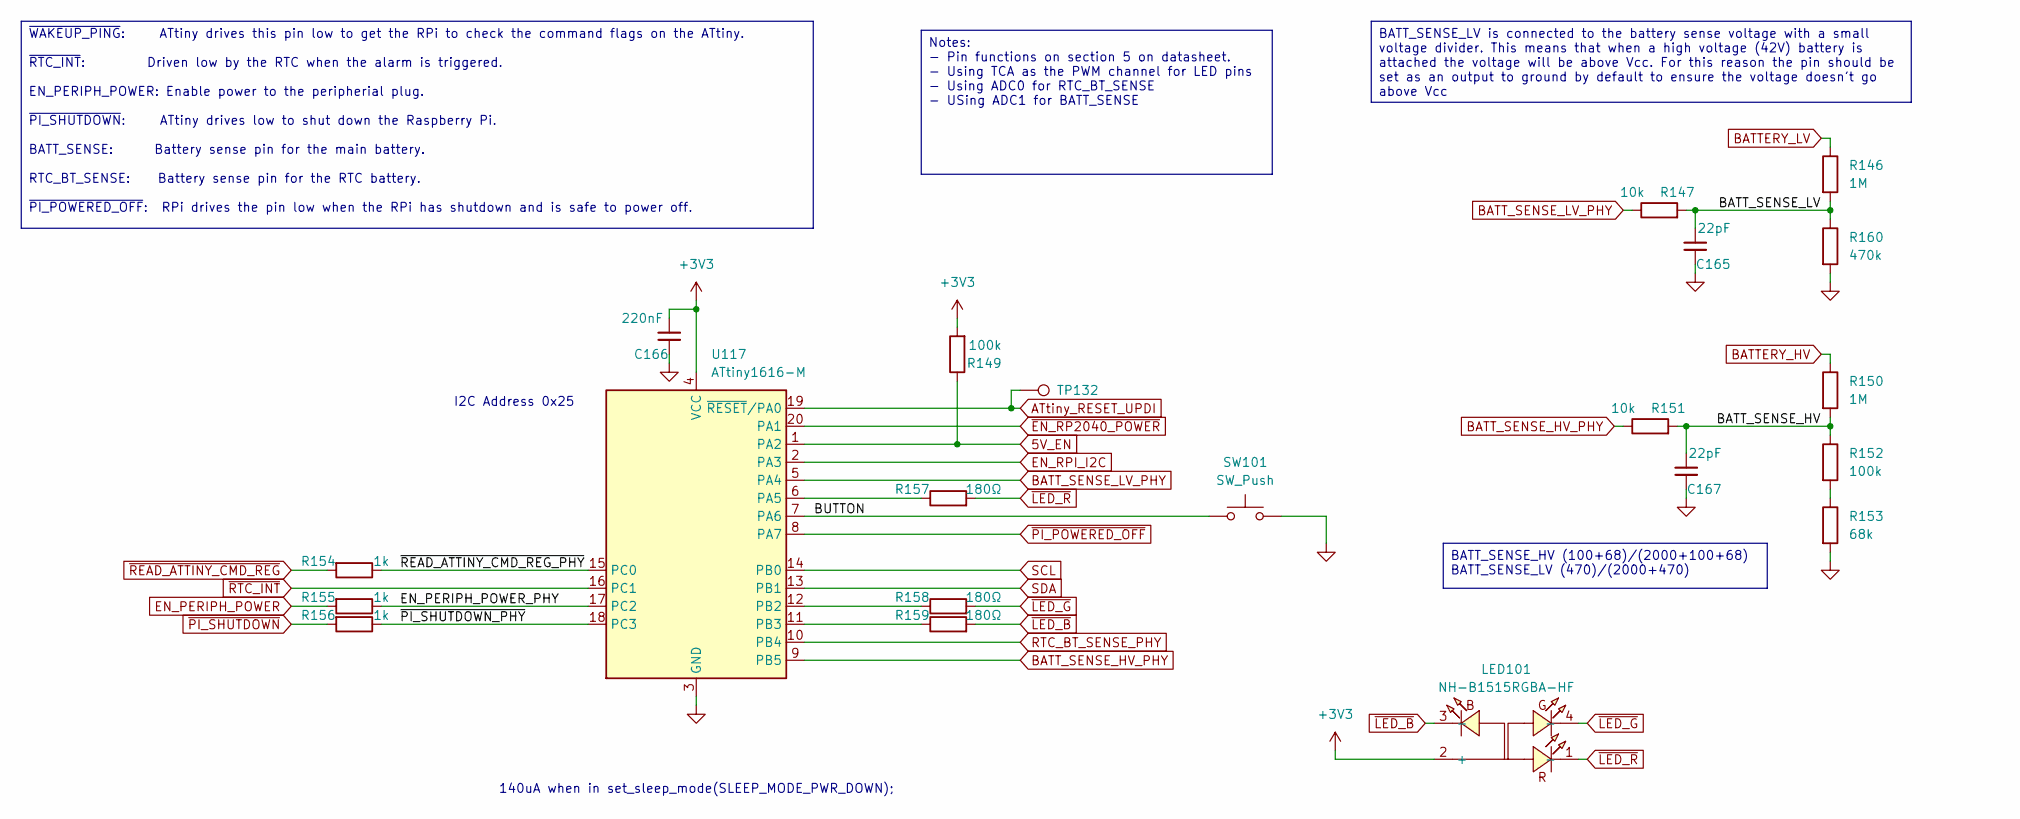
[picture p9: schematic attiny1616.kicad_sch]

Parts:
C165, C167: 22pF; C_0402_1005Metric; LCSC Part C1555
C166: 220nF; C_0402_1005Metric; LCSC Part C16772
LED101: NH-B1515RGBA-HF; LED-ARRAY-SMD_4P-L1.6-W1.5-TL_NH-B1515RGBA; LCSC Part C2874115
R146, R150: 1M; R_0603_1608Metric; LCSC Part C326730
R147, R151: 10k; R_0402_1005Metric; LCSC Part C25744
R149: 100k; R_0402_1005Metric; LCSC Part C25741
R152: 100k; R_0402_1005Metric; LCSC Part C445619
R153: 68k; R_0402_1005Metric; LCSC Part C445618
R154, R155, R156: 1k; R_0402_1005Metric; LCSC Part C11702
R157, R158, R159: 180Ω; R_0402_1005Metric; LCSC Part C38941
R160: 470k; R_0402_1005Metric; LCSC Part C319591
SW101: SW_Push; SW_PUSH_6mm; LCSC Part C4364951
TP132: TestPoint; TestPoint_Pad_D1.0mm
U117: ATtiny1616-M; VQFN-20-1EP_3x3mm_P0.4mm_EP1.7x1.7mm; LCSC Part C507118

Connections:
5V_EN: R149.1, U117.1 (PA2); also elsewhere on the board
+3V3: C166.2, LED101.2 (+), R149.2, U117.4 (VCC); also elsewhere on the board
/ATtiny1616/BATT_SENSE_HV: C167.2, R150.2, R151.2, R152.1
/ATtiny1616/BATT_SENSE_LV: C165.2, R146.2, R147.2, R160.1
/ATtiny1616/BUTTON: SW101.1, U117.7 (PA6)
/ATtiny1616/EN_PERIPH_POWER_PHY: R155.1, U117.17 (PC2)
/ATtiny1616/~PI_SHUTDOWN_PHY: R156.1, U117.18 (PC3)
/ATtiny1616/~READ_ATTINY_CMD_REG_PHY: R154.1, U117.15 (PC0)
ATtiny_RESET_UPDI: TP132.1 (1_1), U117.19 (~RESET/PA0); also elsewhere on the board
BATTERY_HV: R150.1; also elsewhere on the board
BATTERY_LV: R146.1; also elsewhere on the board
BATT_SENSE_HV_PHY: R151.1, U117.9 (PB5)
BATT_SENSE_LV_PHY: R147.1, U117.5 (PA4)
EN_PERIPH_POWER: R155.2; also elsewhere on the board
EN_RPI_I2C: U117.2 (PA3); also elsewhere on the board
GND: C165.1, C166.1, C167.1, R153.2, R160.2, SW101.2, U117.3 (GND), U117.21 (GND); also elsewhere on the board
unnamed: R152.2, R153.1
unnamed: R157.1, U117.6 (PA5)
unnamed: R158.1, U117.12 (PB2)
unnamed: R159.1, U117.11 (PB3)
RTC_BT_SENSE_PHY: U117.10 (PB4); also elsewhere on the board
SCL: U117.14 (PB0); also elsewhere on the board
SDA: U117.13 (PB1); also elsewhere on the board
~EN_RP2040_POWER: U117.20 (PA1); also elsewhere on the board
~LED_B: LED101.3 (-), R159.2
~LED_G: LED101.4 (-), R158.2
~LED_R: LED101.1 (-), R157.2
~PI_POWERED_OFF: U117.8 (PA7); also elsewhere on the board
~PI_SHUTDOWN: R156.2; also elsewhere on the board
~READ_ATTINY_CMD_REG: R154.2; also elsewhere on the board
~RTC_INT: U117.16 (PC1); also elsewhere on the board

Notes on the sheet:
140uA when in set_sleep_mode(SLEEP_MODE_PWR_DOWN);
I2C Address 0x25
BATT_SENSE_LV is connected to the battery sense voltage with a small voltage divider. This means that when a high voltage (42V) battery is attached the voltage will be above Vcc. For this reason the pin should be set as an output to ground by default to ensure the voltage doesn't go above Vcc
BATT_SENSE_HV (100+68)/(2000+100+68) BATT_SENSE_LV (470)/(2000+470)
~{WAKEUP_PING}: ATtiny drives this pin low to get the RPi to check the command flags on the ATtiny. ~{RTC_INT}: Driven low by the RTC when the alarm is triggered. EN_PERIPH_POWER: Enable power to the peripherial plug. ~{PI_SHUTDOWN}: ATtiny drives low to shut down the Raspberry Pi. BATT_SENSE: Batt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
Notes: - Pin functions on section 5 on datasheet. - Using TCA as the PWM channel for LED pins - Using ADC0 for RTC_BT_SENSE - USing ADC1 for BATT_SENSE

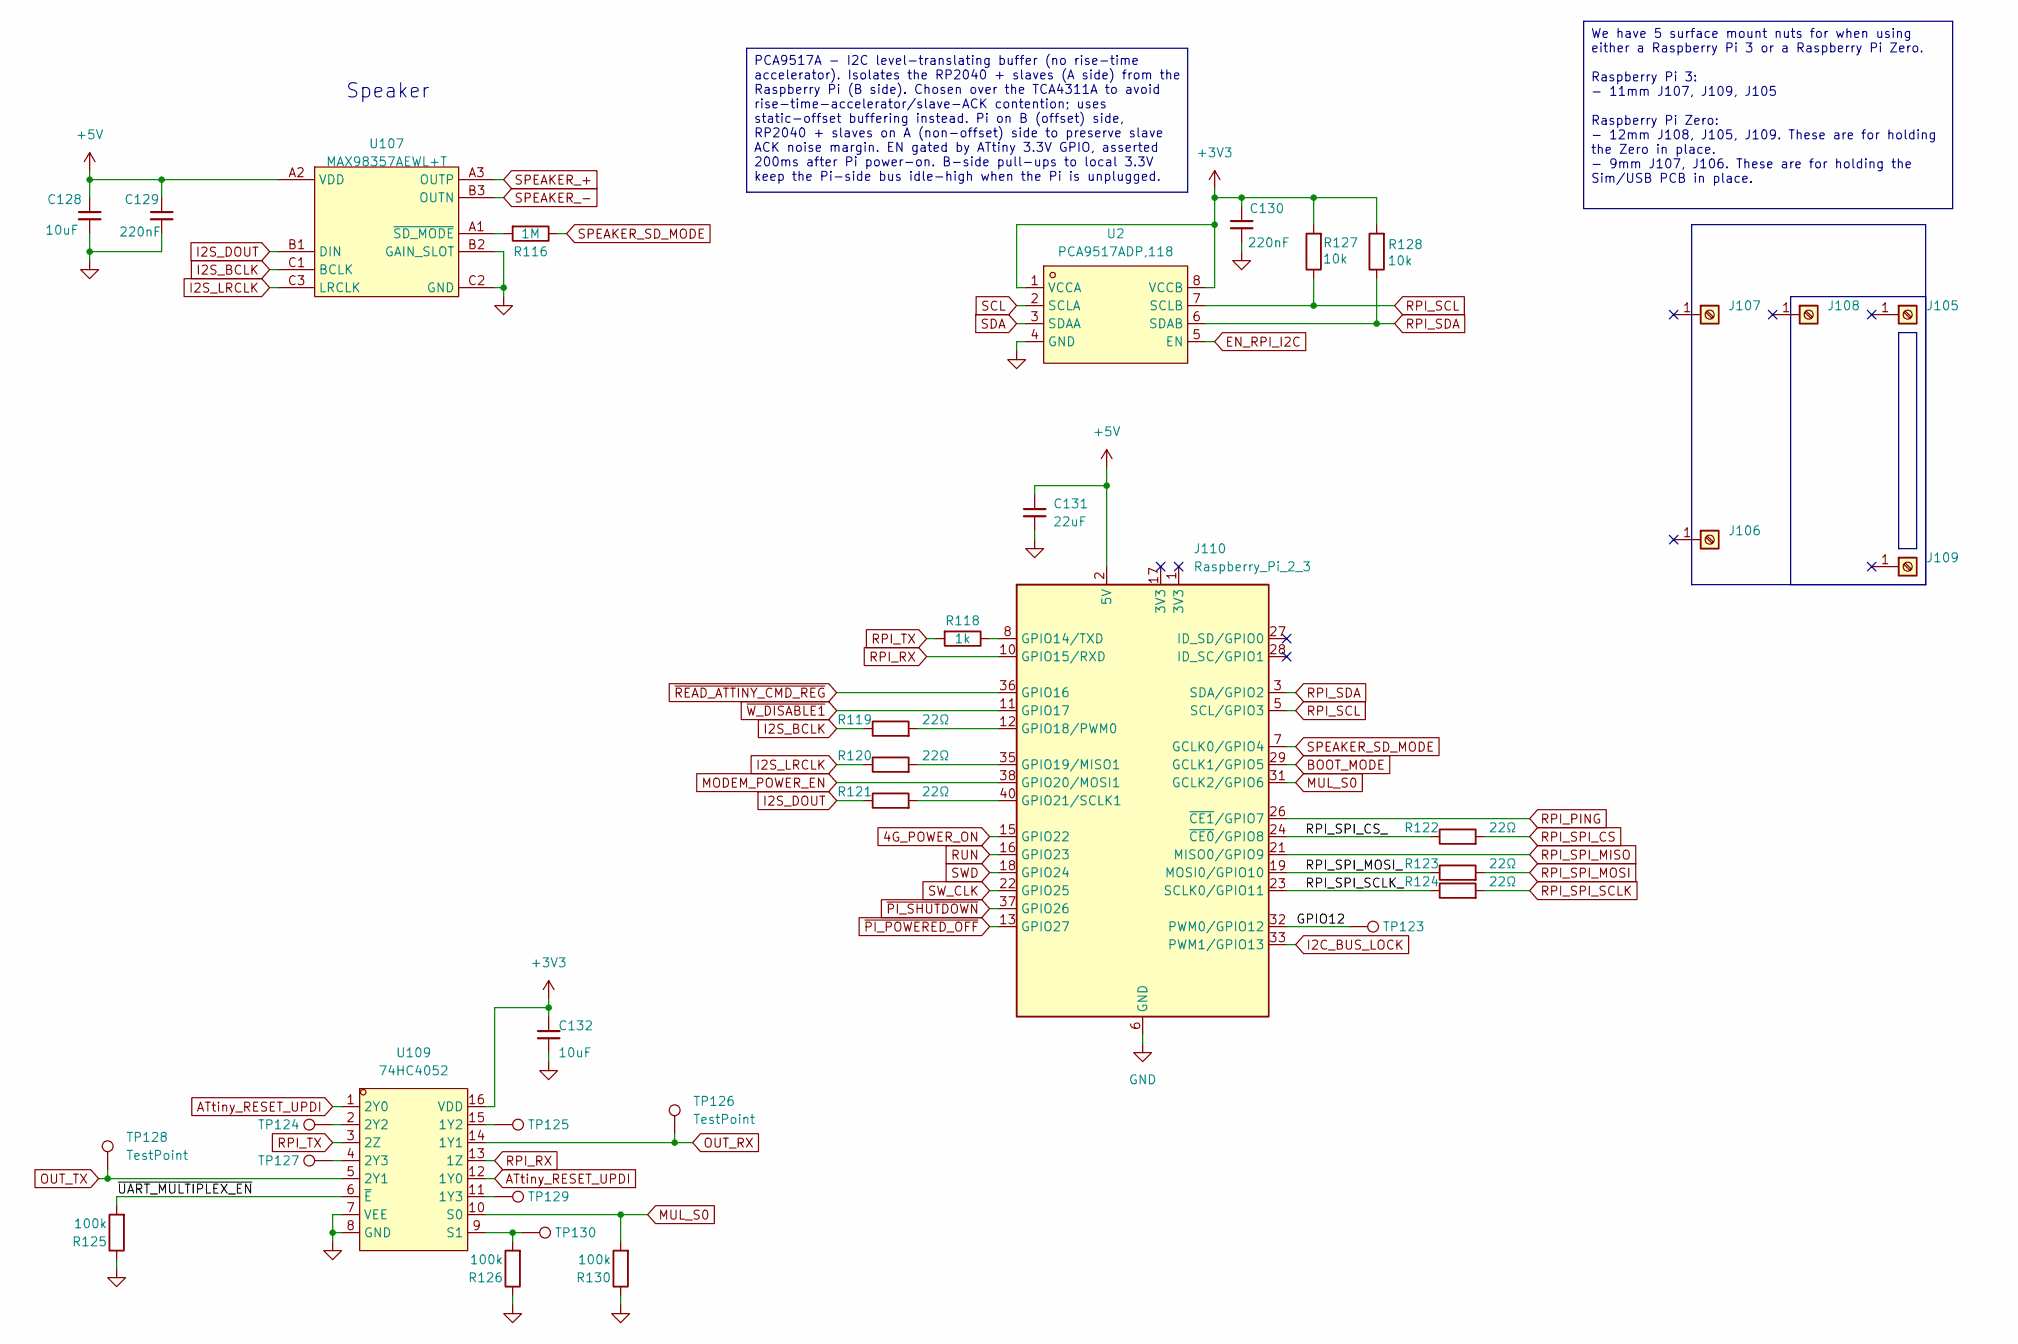
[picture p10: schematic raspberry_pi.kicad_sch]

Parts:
C128, C132: 10uF; C_0603_1608Metric; LCSC Part C19702
C129, C130: 220nF; C_0402_1005Metric; LCSC Part C16772
C131: 22uF; C_0603_1608Metric; LCSC Part C86295
J105, J106, J107, J108, J109: Screw_Terminal_01x01; smd_nut_SMTSO25; LCSC Part C2915630
J110: Raspberry_Pi_2_3; rpi-throughhole-socket; LCSC Part C350295
R116: 1M; R_0603_1608Metric; LCSC Part C326730
R118: 1k; R_0402_1005Metric; LCSC Part C11702
R119, R120, R121, R122, R123, R124: 22Ω; R_0402_1005Metric; LCSC Part C25092
R125, R126, R130: 100k; R_0402_1005Metric; LCSC Part C25741
R127, R128: 10k; R_0402_1005Metric; LCSC Part C25744
TP123, TP124, TP125, TP127, TP129, TP130: TestPoint; TP
TP126, TP128: TestPoint; TestPoint_Pad_D1.0mm
U2: PCA9517ADP,118; MSOP-8_3x3mm_P0.65mm; MPN PCA9517ADP,118; LCSC Part C80799
U107: MAX98357AEWL+T; WLP-9_L1.4-W1.3-P0.40-R3-C3-BR; JLC Part Extended Part
U109: 74HC4052; SOIC-16_3.9x9.9mm_P1.27mm; LCSC Part C11350

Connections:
4G_POWER_ON: J110.15 (GPIO22); also elsewhere on the board
+3V3: C130.2, C132.1, R127.2, R128.2, U2.1 (VCCA), U2.8 (VCCB), U109.16 (VDD); also elsewhere on the board
+5V: C128.1, C129.2, C131.1, J110.2 (5V), J110.4 (5V), U107.A2 (VDD); also elsewhere on the board
/Raspberry_Pi/GPIO12: J110.32 (PWM0/GPIO12), TP123.1 (1_1)
/Raspberry_Pi/RPI_SPI_CS_: J110.24 (~CE0/GPIO8), R122.1
/Raspberry_Pi/RPI_SPI_MOSI_: J110.19 (MOSI0/GPIO10), R123.1
/Raspberry_Pi/RPI_SPI_SCLK_: J110.23 (SCLK0/GPIO11), R124.1
/Raspberry_Pi/~UART_MULTIPLEX_EN: R125.2, U109.6 (~E)
ATtiny_RESET_UPDI: U109.1 (2Y0), U109.12 (1Y0); also elsewhere on the board
BOOT_MODE: J110.29 (GCLK1/GPIO5); also elsewhere on the board
EN_RPI_I2C: U2.5 (EN); also elsewhere on the board
GND: C128.2, C129.1, C130.1, C131.2, C132.2, J110.6 (GND), J110.9 (GND), J110.14 (GND), J110.20 (GND), J110.25 (GND), J110.30 (GND), J110.34 (GND), J110.39 (GND), R125.1, R126.1, R130.1, U2.4 (GND), U107.B2 (GAIN_SLOT), U107.C2 (GND), U109.7 (VEE), U109.8 (GND); also elsewhere on the board
I2C_BUS_LOCK: J110.33 (PWM1/GPIO13); also elsewhere on the board
I2S_BCLK: R119.1, U107.C1 (BCLK)
I2S_DOUT: R121.1, U107.B1 (DIN)
I2S_LRCLK: R120.1, U107.C3 (LRCLK)
MODEM_POWER_EN: J110.38 (GPIO20/MOSI1); also elsewhere on the board
MUL_S0: J110.31 (GCLK2/GPIO6), R130.2, U109.10 (S0)
unnamed: J110.8 (GPIO14/TXD), R118.1
unnamed: J110.12 (GPIO18/PWM0), R119.2
unnamed: J110.35 (GPIO19/MISO1), R120.2
unnamed: J110.40 (GPIO21/SCLK1), R121.2
unnamed: R116.2, U107.A1 (~SD_MODE)
unnamed: TP125.1 (1_1), U109.15 (1Y2)
unnamed: TP129.1 (1_1), U109.11 (1Y3)
unnamed: TP124.1 (1_1), U109.2 (2Y2)
unnamed: TP127.1 (1_1), U109.4 (2Y3)
unnamed: R126.2, TP130.1 (1_1), U109.9 (S1)
OUT_RX: TP126.1 (1_1), U109.14 (1Y1); also elsewhere on the board
OUT_TX: TP128.1 (1_1), U109.5 (2Y1); also elsewhere on the board
RPI_PING: J110.26 (~CE1/GPIO7); also elsewhere on the board
RPI_RX: J110.10 (GPIO15/RXD), U109.13 (1Z)
RPI_SCL: J110.5 (SCL/GPIO3), R127.1, U2.7 (SCLB)
RPI_SDA: J110.3 (SDA/GPIO2), R128.1, U2.6 (SDAB)
RPI_SPI_CS: R122.2; also elsewhere on the board
RPI_SPI_MISO: J110.21 (MISO0/GPIO9); also elsewhere on the board
RPI_SPI_MOSI: R123.2; also elsewhere on the board
RPI_SPI_SCLK: R124.2; also elsewhere on the board
RPI_TX: R118.2, U109.3 (2Z)
RUN: J110.16 (GPIO23); also elsewhere on the board
SCL: U2.2 (SCLA); also elsewhere on the board
SDA: U2.3 (SDAA); also elsewhere on the board
SPEAKER_+: U107.A3 (OUTP); also elsewhere on the board
SPEAKER_-: U107.B3 (OUTN); also elsewhere on the board
SPEAKER_SD_MODE: J110.7 (GCLK0/GPIO4), R116.1
SWD: J110.18 (GPIO24); also elsewhere on the board
SW_CLK: J110.22 (GPIO25); also elsewhere on the board
~PI_POWERED_OFF: J110.13 (GPIO27); also elsewhere on the board
~PI_SHUTDOWN: J110.37 (GPIO26); also elsewhere on the board
~READ_ATTINY_CMD_REG: J110.36 (GPIO16); also elsewhere on the board
~W_DISABLE1: J110.11 (GPIO17); also elsewhere on the board

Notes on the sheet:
Speaker
PCA9517A - I2C level-translating buffer (no rise-time accelerator). Isolates the RP2040 + slaves (A side) from the Raspberry Pi (B side). Chosen over the TCA4311A to avoid rise-time-accelerator/slave-ACK contention; uses static-offset buffering instead. Pi on B (offset) side, RP2040 + slaves on A (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
We have 5 surface mount nuts for when using either a Raspberry Pi 3 or a Raspberry Pi Zero. Raspberry Pi 3: - 11mm J107, J109, J105 Raspberry Pi Zero: - 12mm J108, J105, J109. These are for holding the Zero in place. - 9mm J107, J106. These are for holding the Sim/USB PCB in place.

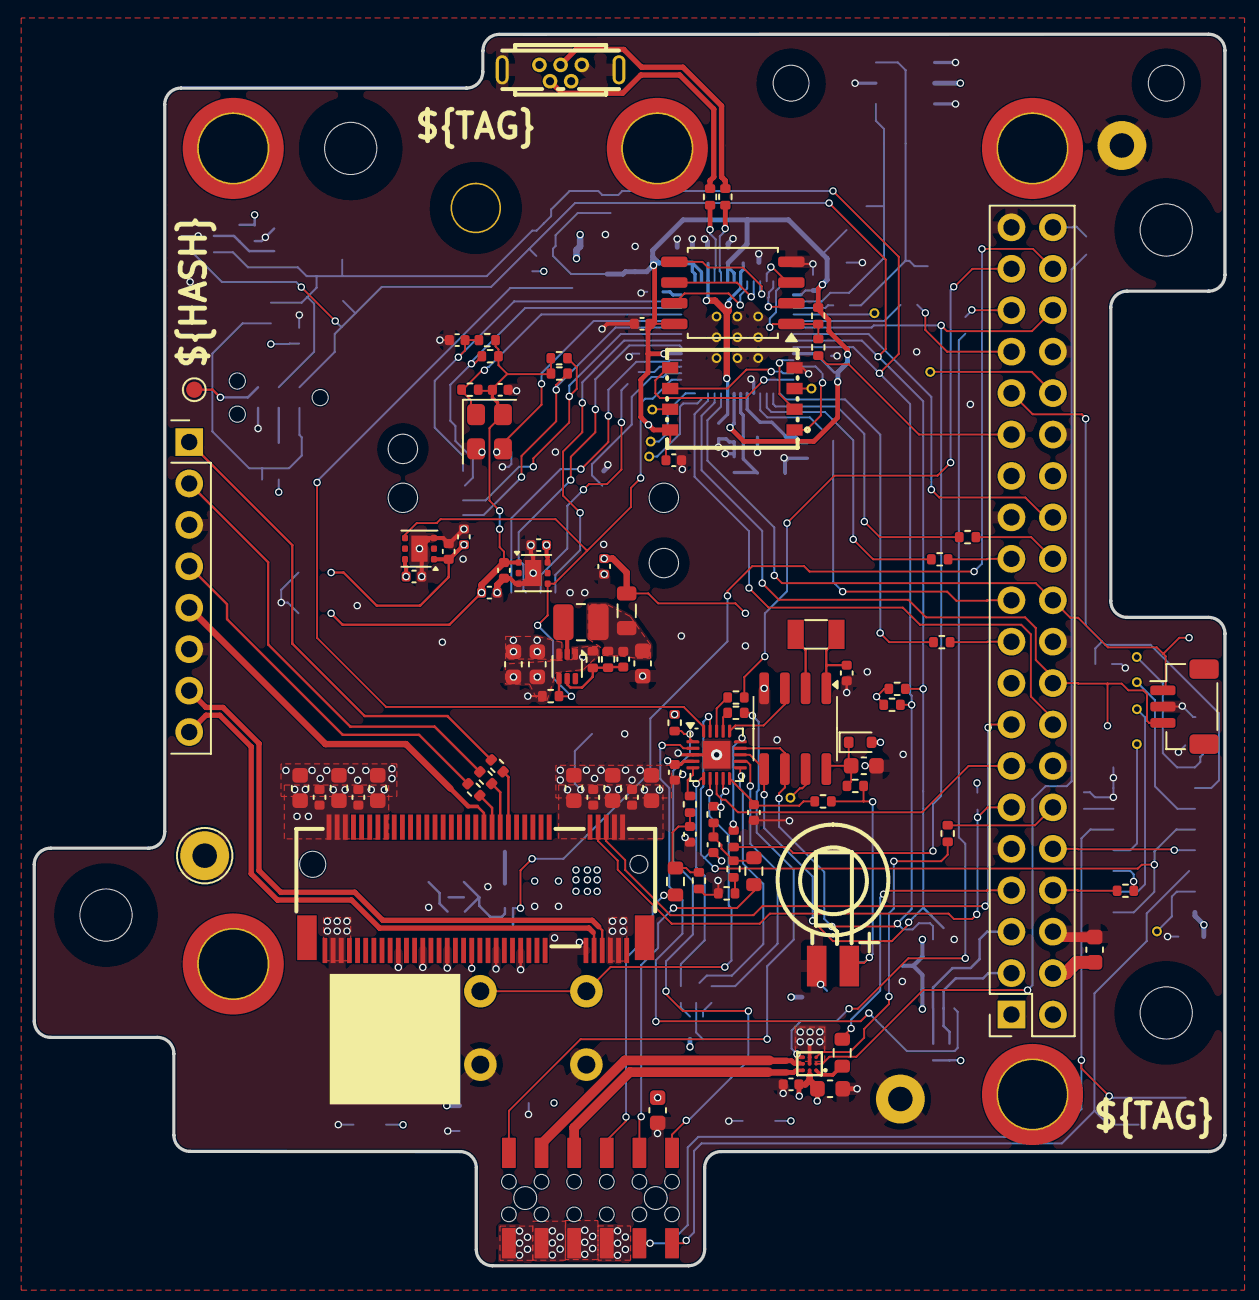
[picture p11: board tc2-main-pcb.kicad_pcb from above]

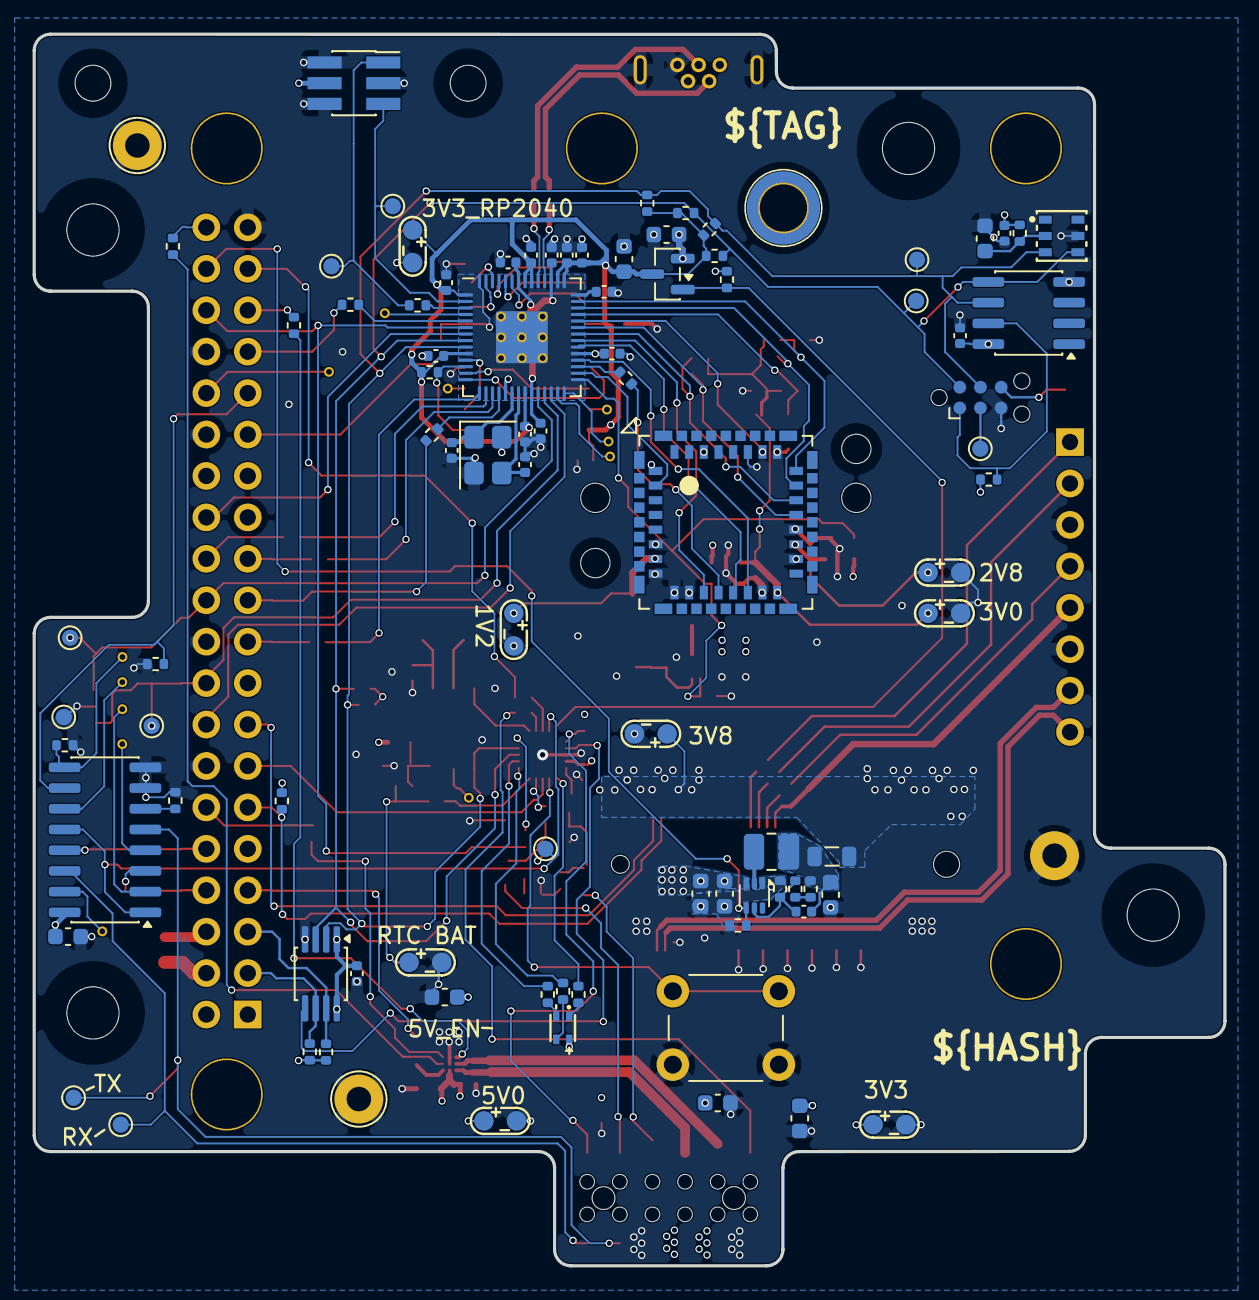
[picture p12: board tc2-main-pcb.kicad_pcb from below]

Board: 6 copper layers, 73.0 x 75.5 mm, 212 parts (108 on the bottom side), 143 nets.

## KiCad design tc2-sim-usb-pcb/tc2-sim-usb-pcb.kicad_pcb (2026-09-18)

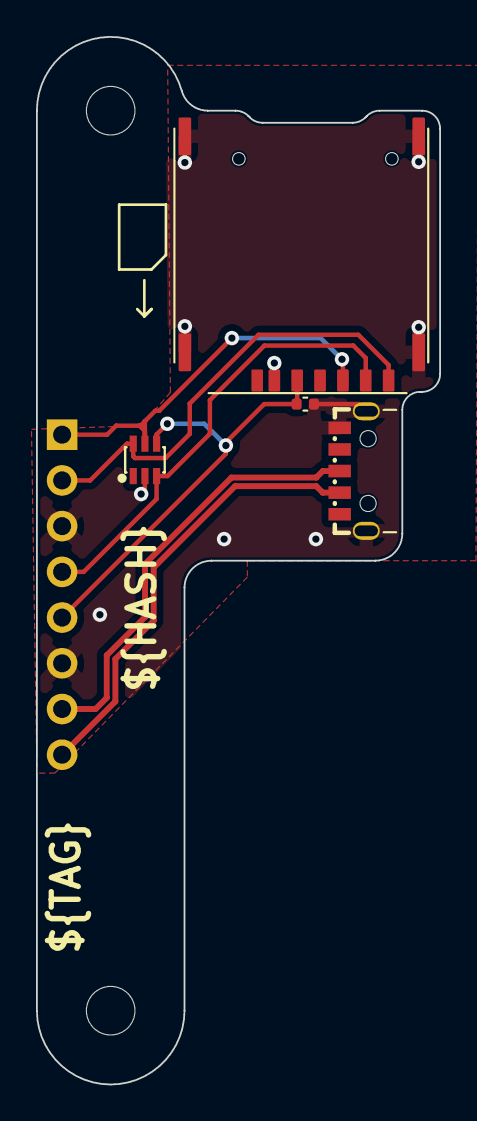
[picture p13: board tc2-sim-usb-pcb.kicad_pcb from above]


Board: 6 copper layers, 22.4 x 58.2 mm, 10 parts (2 on the bottom side), 7 nets.

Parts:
C501: 220nF; C_0402_1005Metric
D501: SMF05CT1G; SOT-363_L2.0-W1.3-P0.65-LS2.1-BR
H501, H502: MountingHole; MountingHole_2.7mm_M2.5
J501: Conn_01x08; Sim_connector
U501, U502: ziptie
U503: K-DYX-010
U504: JLCPCB_QR_8mm
USB501: U-G-M5WS-W-01; MICRO-USB-SMD_U-G-M5WS-W-01

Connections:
4G_USB_D+: J501.7, USB501.3 (D+)
4G_USB_D-: J501.8, USB501.2 (D-)
GND: C501.1, D501.2, J501.3, J501.6, U503.C5 (Gnd), U503.MP, U503.MP_2 (MP), U503.MP_3 (MP), U503.MP_4 (MP), USB501.5 (GND), USB501.6 (SHELL), USB501.7 (SHELL)
USIM_CLK: D501.6, J501.2, U503.C3 (CLK)
USIM_DATA: D501.3, J501.4, U503.C7 (I/O)
USIM_RST: D501.5, J501.1, U503.C2 (RST)
USIM_VDD: C501.2, D501.4, J501.5, U503.C1 (Vcc)

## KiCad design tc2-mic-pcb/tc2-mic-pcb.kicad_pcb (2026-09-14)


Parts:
C401, C402: 100nF; C_0402_1005Metric; LCSC Part C1525
C403: 100nF; C_1206_3216Metric; LCSC Part C170182
C404, C405: 1uF; C_0402_1005Metric; LCSC Part C52923
J401: Conn_02x03_Odd_Even; PinHeader_2x03_P1.27mm_Vertical_SMD; LCSC Part C5160759
J402, J403: Screw_Terminal_01x01; SMD_BD4.4-L4.4-D2.8; LCSC Part C2928186
MK401: SPH0641LU4H-1; Knowles_LGA-5_3.5x2.65mm_0.6mm_NPTH; LCSC Part C2879853
R401, R402, R403: 22Ω; R_0402_1005Metric; LCSC Part C25092
U401: AP7335-18SNG-7; U-DFN2020-6_L2.0-W2.0-P0.65-BL-EP; JLC Part Extended Part
U402: TXS0102DCT; SSOP-8_2.95x2.8mm_P0.65mm; LCSC Part C324082
U403: JLCPCB_QR_8mm

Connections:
+1V8: C401.1, C403.1, C405.1, MK401.5 (VDD), U401.4 (OUT), U402.3 (VCCA)
+3V3: C402.1, C404.1, J401.4, U401.1 (EN), U401.3 (IN), U402.6 (OE), U402.7 (VCCB)
/CLOCK: MK401.4 (CLOCK), R401.1
/CLOCK_PHY: R401.2, U402.5 (A1)
/DATA: R402.2, U402.4 (A2)
/DATA_PHY: MK401.1 (DATA), R402.1
/PDM_DATA_PHY: R403.1, U402.1 (B2)
GND: C401.2, C402.2, C403.2, C404.2, C405.2, J401.2, J401.3, J401.6, MK401.2 (SEL), MK401.3 (GND), U401.2 (GND), U401.7 (GND), U402.2 (GND)
PDM_CLOCK: J401.1, U402.8 (B1)
PDM_DATA: J401.5, R403.2

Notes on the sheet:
Use Class 1 Capacitor as specified in the Mic Datasheet
Microphone
Screw nut, 7mm height
1.27 2x3P Socket, 4.6mm height: C3975129 1.27 2x3P Pins, 2.2mm height: C5160759 Total height 6.8mm


Board: 2 copper layers, 39.0 x 15.5 mm, 15 parts (0 on the bottom side), 10 nets.

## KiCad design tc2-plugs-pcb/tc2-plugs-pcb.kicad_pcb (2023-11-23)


Board: 4 copper layers, 65.0 x 28.3 mm, 65 parts (0 on the bottom side), 35 nets.

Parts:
C101, C102, C103, C104, C106, C107: 22uF; C_0805_2012Metric
C105: 220uF; CP_Elec_8x10
C108, C129: 10uF; C_0603_1608Metric
C109, C110, C111, C112, C119, C120: 1nF; C_0402_1005Metric
C113, C114: 47pF; C_0402_1005Metric
C115, C116: 10nF; C_0402_1005Metric
C117, C118: 100nF; C_0402_1005Metric
C121, C122, C123, C124, C125, C126, C127, C128: 22uF; C_0603_1608Metric
D101: D_Zener; LL-34_L3.5-W1.5-RD
D102, D103: D_Shockley; D_SMA
FB1, FB2: FerriteBead; L_0805_2012Metric
J101: JCON_M16_2+4Pin; jcon-2+4pin-m16
J102: JCON_M16_04Pin; jcon-4pin_m16
J104: Conn_02x06_Odd_Even; PinHeader_2x06_P2.00mm_Horizontal
L101, L102: 6.8uF; IND-SMD_L8.0-W8.0_1217AS
Q1: AO3400A; SOT-23
Q101, Q102: Q_PMOS_GSD; SOT-23
R1, R104, R110, R112, R113: 100k; R_0402_1005Metric
R101, R115: 2M; R_1210_3225Metric
R102: 150k; R_0805_2012Metric
R103: 22k; R_0805_2012Metric
R105, R106: 33k; R_0402_1005Metric
R107: 150k; R_0402_1005Metric
R108, R111: 22k; R_0402_1005Metric
R109: 10k; R_0402_1005Metric
R114: 1k; R_0402_1005Metric
R116: 560k; R_1206_3216Metric
R117: 33k; R_0603_1608Metric
TP101, TP102, TP103: TestPoint_2Pole; test-point-2p
U101, U102: TPS54331; SO-8_3.9x4.9mm_P1.27mm

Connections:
5V_EN: J104.1, U101.3 (EN)
+3V3: FB2.2, J104.10, TP102.2
+5V: FB1.2, J104.8, TP103.2
+12V: C101.1, C102.1, C103.1, C104.1, C105.1, C106.1, C107.1, C109.1, C110.1, C129.1, D101.1 (K), Q101.2 (S), Q102.2 (S), R113.2, U101.2 (VIN), U102.2 (VIN)
/3V3_PF: C120.1, C122.1, C124.1, C126.1, C128.1, FB2.1, L102.2, R112.1
/5V0_PF: C119.1, C121.1, C123.1, C125.1, C127.1, FB1.1, L101.2, R110.1
/+Batt: J102.4, R101.1, R115.1
/SW_3V3: C118.2, D103.1 (K), L102.1, U102.8 (PH)
/SW_5V: C117.2, D102.1 (K), L101.1, U101.8 (PH)
BATT_SENSE_HV: J104.3, R101.2, R102.1
BATT_SENSE_LV: J104.5, R115.2, R116.1
EN_PERIPH_POWER: J104.11, R114.1
GND: C101.2, C102.2, C103.2, C104.2, C105.2, C106.2, C107.2, C108.2, C109.2, C110.2, C111.2, C112.2, C113.2, C114.2, C115.2, C116.2, C119.2, C120.2, C121.2, C122.2, C123.2, C124.2, C125.2, C126.2, C127.2, C128.2, C129.2, D102.2 (A), D103.2 (A), J101.1, J102.1, J104.6, J104.12, Q1.2 (S), R1.1, R103.2, R104.2, R107.1, R109.2, R111.1, R117.2, TP101.1, TP102.1, TP103.1, U101.7 (GND), U102.7 (GND)
unnamed: C111.1, R105.2
unnamed: C112.1, R106.2
unnamed: D101.2 (A), Q101.1 (G), R104.1
unnamed: Q1.3 (D), Q102.1 (G), R113.1
unnamed: Q1.1 (G), R1.2, R114.2
unnamed: R102.2, R103.1
unnamed: R108.1, R109.1
unnamed: R116.2, R117.1
unnamed: C117.1, U101.1 (BOOT)
unnamed: C113.1, R105.1, U101.6 (COMP)
unnamed: C115.1, U101.4 (SS)
unnamed: R107.2, R110.2, R111.2, U101.5 (VSENSE)
unnamed: C118.1, U102.1 (BOOT)
unnamed: C114.1, R106.1, U102.6 (COMP)
unnamed: C116.1, U102.4 (SS)
unnamed: R108.2, R112.2, U102.5 (VSENSE)
OUT_RX: J101.2, J104.2
OUT_TX: J101.3, J104.4
SPEAKER_+: J101.4, J104.9
SPEAKER_-: J101.5, J104.7
VIN: J102.2, Q101.3 (D)
VOUT: C108.1, J101.6, Q102.3 (D), TP101.2

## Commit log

2022-11-13 WIP 2
    [SIM7600G_M.2.kicad_sch, lepton.kicad_sch, plug-pcb-drawings.FCStd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]
2023-04-17 Low power WIP
    [lepton.kicad_sch, modem.kicad_sch, raspberry_pi.kicad_sch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]
2023-05-10 Low power version WIP
    [SIM7600G_M.2.kicad_sch, lepton.kicad_sch, modem.kicad_sch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]
2023-05-25 file tidy up
    [Drawings-MirroredSketch.dxf, Drawings-PCB.dxf, Drawings-RPi.dxf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]
2023-05-30 Clean up of files and updated drawings for PCBs
    [7mm_2mm_nut.FCStd, lepton.kicad_sch, modem.kicad_sch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]
2023-06-15 Version 2 WIP
    [plug-pcb-drawings-edge-cuts.dxf, raspberry_pi.kicad_sch, tc2-main-pcb.kicad_pcb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]
2023-06-27 Thermal camera V2 WIP
    [raspberry_pi.kicad_sch, tc2-main-pcb.kicad_pcb, tc2-main-pcb.kicad_sch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]
2023-09-04 P2 milestone
    [lepton.kicad_sch, modem.kicad_sch, raspberry_pi.kicad_sch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]
2023-11-23 P3-Nov release
    [attiny1616.kicad_sch, lepton.kicad_sch, modem.kicad_sch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]
2023-11-23 Update boarder for power PCB
    [tc2-plugs-buck-boost-pcb.FCStd]
2024-05-04 Small update for v0.4.1
    [attiny1616.kicad_sch, lepton.kicad_sch, modem.kicad_sch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]
2024-05-09 update for v0.4.1
    [tc2-main-pcb.kicad_pcb]
2024-05-30 panelize WIP
    [attiny1616.kicad_sch, tc2-main-pcb.kicad_pcb, tc2-main-pcb.kicad_sch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]
2024-06-12 Adding panel
    [attiny1616.kicad_sch, raspberry_pi.kicad_sch, tc2-main-pcb.kicad_pcb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]
2024-08-19 Update to use touch sensor
    [attiny1616.kicad_sch, lepton.kicad_sch, modem.kicad_sch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]
2024-09-06 Small updates
    [attiny1616.kicad_sch, tc2-plugs-buck-boost-pcb.kicad_pcb, tc2-plugs-buck-boost-pcb.kicad_sch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]
2024-09-07 Change to through hole connector and add simcard PCB to pannel
    [attiny1616.kicad_sch, raspberry_pi.kicad_sch, tc2-main-pcb.kicad_pcb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]
2024-09-28 Version v0.7.0
    [tc2-main-pcb.kicad_pcb, tc2-main-pcb.kicad_sch, tc2-plugs-buck-boost-pcb.kicad_pcb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]
2024-10-25 version v0.7.1
    [tc2-main-pcb.kicad_pcb, tc2-main-pcb.kicad_sch, tc2-plugs-buck-boost-pcb.kicad_pcb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]
2025-02-09 Fixed panel tabs
    [tc2-main-pcb.kicad_pcb, tc2-plugs-buck-boost-pcb.kicad_pcb, tc2-plugs-buck-boost-pcb.kicad_sch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]
2025-04-27 Upgraded to new kicad version
    [attiny1616.kicad_sch, lepton.kicad_sch, modem.kicad_sch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]
2025-04-27 Tidy up for making an order for v0.7.3
    [attiny1616.kicad_sch, lepton.kicad_sch, modem.kicad_sch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]
2026-08-16 Upgrade to KiCAD 10
    [attiny1616.kicad_sch, lepton.kicad_sch, modem.kicad_sch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]
2026-08-16 Remove auto generated files from git
    [tc2-touch-sensor.FCStd, tc2-touch-sensor.kicad_pcb, tc2-touch-sensor.kicad_sch]
2026-08-17 Fix library
    [raspberry_pi.kicad_sch, tc2-main-pcb.kicad_pcb, tc2-main-pcb.kicad_sch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]
2026-08-17 Fix tc2-panel.py
    [tc2-plugs-buck-boost-pcb.kicad_pcb, tc2-sim-usb-pcb.kicad_pcb]
2026-08-17 Added pannel for microphone pcb
    [tc2-mic-pcb.FCStd, tc2-mic-pcb.kicad_pcb]
2026-08-17 Add 2D barcode for microphone
    [tc2-mic-pcb.kicad_pcb, tc2-mic-pcb.kicad_sch]
2026-08-17 Change file output for generated PCBs
2026-08-17 Remove old files
    [tc2-plugs-pcb.FCStd, tc2-plugs-pcb.kicad_pcb, tc2-plugs-pcb.kicad_sch]
2026-08-18 Add JLPCPCB 2D barcode to PCBs
    [tc2-main-pcb.kicad_pcb, tc2-main-pcb.kicad_sch, tc2-mic-pcb.kicad_pcb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]
2026-09-14 Update tc2-micophone panelization
    [tc2-mic-pcb.kicad_pcb]
2026-09-14 Set inductor values
    [tc2-plugs-buck-boost-pcb.kicad_sch]
2026-09-14 Update 5V DC-DC buck-boost
    [tc2-plugs-buck-boost-pcb.kicad_sch]
2026-09-15 Update DC-DC converters
    [attiny1616.kicad_sch, lepton.kicad_sch, modem.kicad_sch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]
2026-09-16 Update schematic
    [attiny1616.kicad_sch, lepton.kicad_sch, modem.kicad_sch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]
2026-09-17 Update layout
    [lepton.kicad_sch, tc2-main-pcb.kicad_pcb, tc2-main-pcb.kicad_sch]
2026-09-17 Add comment about screws to hold lepton 3D print in place
    [lepton.kicad_sch]
2026-09-18 Add git hash to PCBs
    [tc2-main-pcb.kicad_pcb, tc2-mic-pcb.kicad_sch, tc2-plugs-buck-boost-pcb.kicad_pcb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]
2026-09-20 Update component for button to 11mm version not 12mm
    [attiny1616.kicad_sch]
2026-09-22 Add tc2-sim-usb-pi3-pcb to kicad-release
2026-09-22 Fix ERC errors
    [tc2-sim-usb-pi3-pcb.kicad_sch]
2026-09-22 Add panel for tc2-sim-usb-pi3
    [tc2-sim-usb-pi3-pcb.kicad_pcb]
